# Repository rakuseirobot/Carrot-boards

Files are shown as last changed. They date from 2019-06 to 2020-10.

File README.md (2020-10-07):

# Carrot-boards
全自動走行台車の回路図です。
[Carrotの動画はこちら](https://www.youtube.com/watch?v=5gtot_12dCg&ab_channel=DDProjectII)

# Features

* STM32F7 Discovery用のボード
* KeyHolder FT234を使ったUSBシリアル変換器
* UI 操作板の基板データ　F4書き込みや、電源、リセットスイッチなどを載せる
* mainboard main基板　raspberryPiやSTM32F4が載ります

# Requirement

* Autodesk Eagleを用いて作成しました。

F4のプログラムは[こちら](https://github.com/rakuseirobot/Carrot-F4-motor)
RaspberryPiのプログラムは[こちら](https://github.com/rakuseirobot/Carrot-ROS-src)

# Note

mainboardに搭載されているSTM32F446に配線されているイーサネットICはLANコネクタを向きを逆に配置してしまったこととおそらく配線を間違ってしまったこともあり、実装すると3.3Vラインがショートしてしまうため注意してください。

# Author

* Shun Kayaki
* Kyushu institute of Technology
* shun@guetan.dev

# License

Copyright (c) 2019 Shun Kayaki
Released under the MIT license

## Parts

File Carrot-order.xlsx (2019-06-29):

部品名 | URL | 何個入り | 何個必要/板 | 何枚分？ | 何個必要 | 必要パック数 | 予備個数 | 購入パック数 | 購入個数 | 一パック当たりの値段 | 計 | 一枚当たりの計 | 備考 | 16440.44
51Ω チップ抵抗 | https://www.monotaro.com/g/04248178/?t.q=51%83%B6%81%40%83%60%83b%83v | 100 | 6 | 2 | 12 | 0.12 | 88 | 1 | 100 | 599 | 599 | 299.5
イーサネットICDP83848 | https://jp.rs-online.com/web/p/physical-layer-transceivers/6515738/ | 1 | 1 | 2 | 2 | 2 | 0 | 2 | 2 | 630.72 | 1261.44 | 630.72
 |  |  |  |  | 0 | #DIV/0! |  | #DIV/0! | 0 |  | #DIV/0! | #DIV/0!
 |  |  |  |  | 0 | #DIV/0! |  | #DIV/0! | 0 |  | #DIV/0! | #DIV/0!
 |  |  |  |  | 0 | #DIV/0! |  | #DIV/0! | 0 |  | #DIV/0! | #DIV/0!
CANコントローラー MCP2561 | http://akizukidenshi.com/catalog/g/gI-12483/ | 1 | 1 | 2 | 2 | 2 | 2 | 4 | 4 | 90 | 360 | 180
RS485コントローラーLTC485 | http://akizukidenshi.com/catalog/g/gI-02792/ | 1 | 1 | 2 | 2 | 2 | 2 | 4 | 4 | 150 | 600 | 300
50MHzクリスタル | http://akizukidenshi.com/catalog/g/gP-09358/ | 2 | 1 | 2 | 2 | 1 | 0 | 1 | 2 | 300 | 300 | 150
Nch MOSFET | http://akizukidenshi.com/catalog/g/gI-09931/ | 1 | 2 | 2 | 4 | 4 | 1 | 5 | 5 | 50 | 250 | 125
LANコネクタ | http://akizukidenshi.com/catalog/g/gP-04809/ | 1 | 1 | 2 | 2 | 2 |  | 2 | 2 | 200 | 400 | 200
DCファン | http://akizukidenshi.com/catalog/g/gP-14184/ | 1 | 1 | 2 | 2 | 2 |  | 2 | 2 | 280 | 560 | 280
ポリスイッチ350mA | http://akizukidenshi.com/catalog/g/gP-12900/ | 5 | 1 | 1 | 1 | 0.2 | 4 | 1 | 5 | 100 | 100 | 100
ポリスイッチ0.4A | http://akizukidenshi.com/catalog/g/gP-13077/ | 1 | 1 | 1 | 1 | 1 | 1 | 2 | 2 | 30 | 60 | 60
VH2ピン 基板側 | http://akizukidenshi.com/catalog/g/gC-12815/ | 1 | 4 | 2 | 8 | 8 | 1 | 9 | 9 | 10 | 90 | 45
VH2ピン 線側 | http://akizukidenshi.com/catalog/g/gC-12811/ | 1 | 10 | 1 | 10 | 10 |  | 10 | 10 | 7 | 70 | 70
VH3ピン 基板側 | http://akizukidenshi.com/catalog/g/gC-12816/ | 1 | 5 | 2 | 10 | 10 | 4 | 14 | 14 | 10 | 140 | 70
VH3ピン 線側 | http://akizukidenshi.com/catalog/g/gC-12812/ | 1 | 10 | 1 | 10 | 10 |  | 10 | 10 | 8 | 80 | 80
VH コンタクト | http://akizukidenshi.com/catalog/g/gC-12819/ | 10 | 10 | 10 | 100 | 10 |  | 10 | 100 | 50 | 500 | 50
4.7uF | http://akizukidenshi.com/catalog/g/gP-13605/ | 20 | 2 | 2 | 4 | 0.2 | 16 | 1 | 20 | 160 | 160 | 80
22pF | http://akizukidenshi.com/catalog/g/gP-13313/ | 40 | 2 | 2 | 4 | 0.1 | 36 | 0 | 40 | 100 | 0 | 0 | ある
22uF | http://akizukidenshi.com/catalog/g/gP-08240/ | 10 | 2 | 2 | 4 | 0.4 | 6 | 1 | 10 | 120 | 120 | 60
10uF | http://akizukidenshi.com/catalog/g/gP-13388/ | 10 | 2 | 2 | 4 | 0.4 | 6 | 0 | 10 | 150 | 0 | 0 | ある
100uF チップ電解 | http://akizukidenshi.com/catalog/g/gP-06855/ | 1 | 3 | 2 | 6 | 6 | 1 | 4 | 7 | 150 | 600 | 300 | ４こある
タクトスイッチ黄色 | http://akizukidenshi.com/catalog/g/gP-03650/ | 1 | 1 | 2 | 2 | 2 |  | 0 | 2 | 10 | 0 | 0 | ある
タクトスイッチ赤色 | http://akizukidenshi.com/catalog/g/gP-03646/ | 1 | 1 | 2 | 2 | 2 |  | 0 | 2 | 10 | 0 | 0 | ある
4.7kΩ アレイ | http://akizukidenshi.com/catalog/g/gP-04663/ | 100 | 2 | 2 | 4 | 0.04 | 96 | 0 | 100 | 100 | 0 | 0 | ある
圧電ブザー | http://akizukidenshi.com/catalog/g/gP-04119/ | 1 | 1 | 2 | 2 | 2 | 1 | 3 | 3 | 40 | 120 | 60
水晶発振子 8MHz | http://akizukidenshi.com/catalog/g/gP-08667/ | 1 | 1 | 2 | 2 | 2 | 0 | 2 | 2 | 30 | 60 | 30
スライドスイッチ | http://akizukidenshi.com/catalog/g/gP-12723/ | 1 | 4 | 2 | 8 | 8 | 2 | 10 | 10 | 25 | 250 | 125
DCジャック | http://akizukidenshi.com/catalog/g/gC-06730/ | 1 | 1 | 2 | 2 | 2 |  | 0 | 2 | 130 | 0 | 0 | ある
ボックスヘッダ 7*2 | http://akizukidenshi.com/catalog/g/gC-10901/ | 1 | 2 | 2 | 4 | 4 | 3 | 4 | 7 | 25 | 100 | 50 | ある
ムラタDCDCコンバータ | http://akizukidenshi.com/catalog/g/gM-06187/ | 1 | 2 | 2 | 4 | 4 |  | 3 | 4 | 600 | 1800 | 900 | 1個ある
USBA ホスト側 | http://akizukidenshi.com/catalog/g/gC-11551/ | 1 | 1 | 2 | 2 | 2 |  | 2 | 2 | 50 | 100 | 50
20kΩ 多回転 半固定抵抗 | http://akizukidenshi.com/catalog/g/gP-01032/ | 1 | 2 | 2 | 4 | 4 |  | 0 | 4 | 120 | 0 | 0 | ある
RaspberryPi コネクタ | http://akizukidenshi.com/catalog/g/gC-10702/ | 1 | 1 | 2 | 2 | 2 |  | 2 | 2 | 150 | 300 | 150
表面実装タクトスイッチ | http://akizukidenshi.com/catalog/g/gP-06185/ | 5 | 2 | 2 | 4 | 0.8 | 1 | 1 | 5 | 100 | 100 | 50
Pch MOSFET J334 | http://akizukidenshi.com/catalog/g/gI-02846/ | 1 | 4 | 2 | 8 | 8 |  | 8 | 8 | 150 | 1200 | 600
2mmピッチ ピンソケット | http://akizukidenshi.com/catalog/g/gC-03668/ | 1 | 2 | 2 | 4 | 4 |  | 4 | 4 | 30 | 120 | 60
ICソケット 8P | http://akizukidenshi.com/catalog/g/gP-00017/ | 10 | 2 | 2 | 4 | 0.4 | 6 | 1 | 10 | 100 | 100 | 50
ターミナルブロック | http://akizukidenshi.com/catalog/g/gP-01306/ | 1 | 4 | 2 | 8 | 8 |  | 8 | 8 | 20 | 160 | 80
緑色LED入り タクトスイッチ | http://akizukidenshi.com/catalog/g/gP-02009/ | 1 | 1 | 1 | 1 | 1 |  | 1 | 1 | 150 | 150 | 150
赤色LED入り タクトスイッチ | http://akizukidenshi.com/catalog/g/gP-02010/ | 1 | 1 | 1 | 1 | 1 |  | 1 | 1 | 150 | 150 | 150
キースイッチ | http://akizukidenshi.com/catalog/g/gP-07059/ | 1 | 2 | 1 | 2 | 2 |  | 2 | 2 | 100 | 200 | 200
緑色LED トグルスイッチ | http://akizukidenshi.com/catalog/g/gP-07246/ | 1 | 2 | 1 | 2 | 2 |  | 2 | 2 | 200 | 400 | 400
3ピンDIPスイッチ | http://akizukidenshi.com/catalog/g/gP-09992/ | 1 | 1 | 1 | 1 | 1 |  | 1 | 1 | 80 | 80 | 80 | あったと。。
 |  |  |  |  | 0 | #DIV/0! |  | #DIV/0! | 0 |  | #DIV/0! | #DIV/0!
STMF405 | http://akizukidenshi.com/catalog/g/gI-13219/ | 1 | 2 | 1 | 2 | 2 |  | 2 | 2 | 1000 | 2000 | 2000
 |  |  |  |  | 0 | #DIV/0! |  | #DIV/0! | 0 |  | #DIV/0! | #DIV/0!
LCD LED | http://akizukidenshi.com/catalog/g/gI-05318/ | 20 | 1 | 12 | 12 | 0.6 | 8 | 1 | 20 | 200 | 200 | 16.66666667
FT230 | http://akizukidenshi.com/catalog/g/gI-13311/ | 1 | 1 | 10 | 10 | 10 |  | 10 | 10 | 220 | 2200 | 220
ポリスイッチ350mA | http://akizukidenshi.com/catalog/g/gP-12900/ | 5 | 1 | 7 | 7 | 1.4 | 3 | 2 | 10 | 100 | 200 | 28.57142857
白色チップLED | http://akizukidenshi.com/catalog/g/gI-03986/ | 20 | 1 | 1 | 1 | 0.05 | 19 | 1 | 20 | 200 | 200 | 200
青色チップLED | http://akizukidenshi.com/catalog/g/gI-03982/ | 20 | 1 | 1 | 1 | 0.05 | 19 | 0 | 20 | 200 | 0 | 0 | ある
赤色チップLED | http://akizukidenshi.com/catalog/g/gI-03978/ | 20 | 1 | 1 | 1 | 0.05 | 19 | 0 | 20 | 200 | 0 | 0 | ある
 |  |  |  |  | 0 | #DIV/0! |  | #DIV/0! | 0 |  | #DIV/0! | #DIV/0!
 |  |  |  |  | 0 | #DIV/0! |  | #DIV/0! | 0 |  | #DIV/0! | #DIV/0!
 |  |  |  |  | 0 | #DIV/0! |  | #DIV/0! | 0 |  | #DIV/0! | #DIV/0!
 |  |  |  |  | 0 | #DIV/0! |  | #DIV/0! | 0 |  | #DIV/0! | #DIV/0!
 |  |  |  |  | 0 | #DIV/0! |  | #DIV/0! | 0 |  | #DIV/0! | #DIV/0!
 |  |  |  |  | 0 | #DIV/0! |  | #DIV/0! | 0 |  | #DIV/0! | #DIV/0!
 |  |  |  |  | 0 | #DIV/0! |  | #DIV/0! | 0 |  | #DIV/0! | #DIV/0!
 |  |  |  |  | 0 | #DIV/0! |  | #DIV/0! | 0 |  | #DIV/0! | #DIV/0!
 |  |  |  |  | 0 | #DIV/0! |  | #DIV/0! | 0 |  | #DIV/0! | #DIV/0!
 |  |  |  |  |  |  |  |  |  |  | #DIV/0! | #DIV/0!

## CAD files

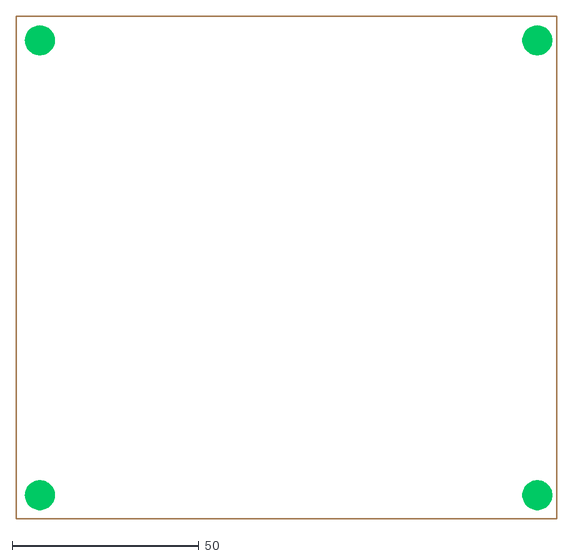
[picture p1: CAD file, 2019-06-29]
mainboard.dxf
144.9 x 134.8

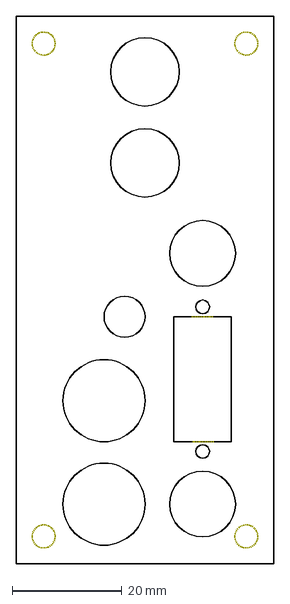
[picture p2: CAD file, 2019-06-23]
UI.dxf
47.0 x 100.0 mm

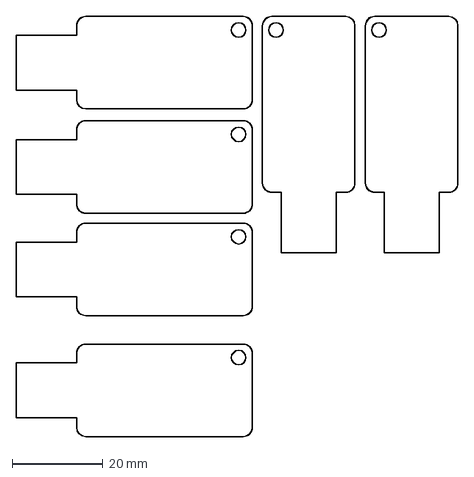
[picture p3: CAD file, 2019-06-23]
KeyHolder.dxf
97.4 x 92.6 mm

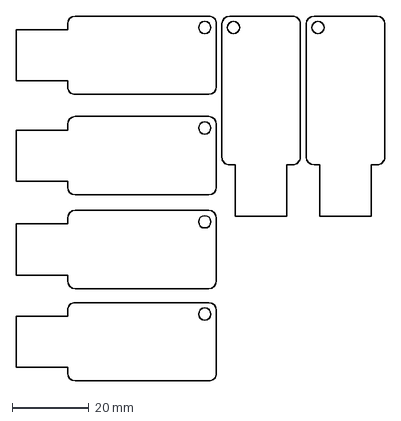
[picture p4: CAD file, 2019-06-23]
UIboard.dxf
95.9 x 95.0 mm

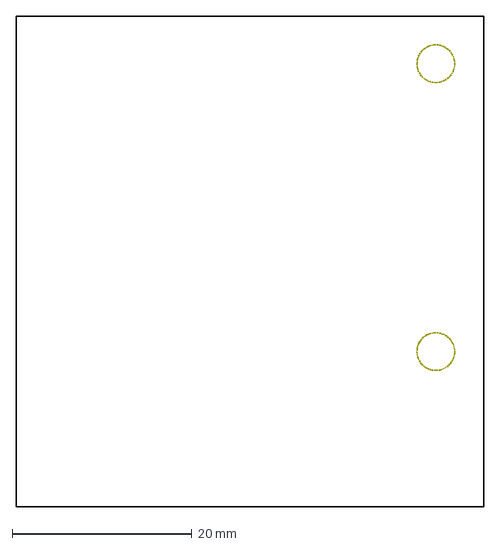
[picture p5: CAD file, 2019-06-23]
F7.dxf
52.1 x 54.6 mm

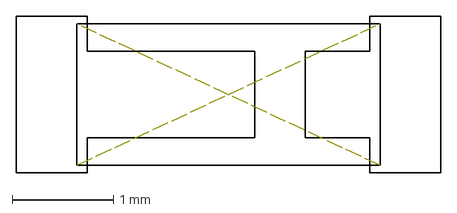
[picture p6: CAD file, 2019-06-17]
NSSW157T.dxf
4.20 x 1.55 mm

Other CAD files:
Carrot.dxf
F7&Key&UI-shape.ipt
F7.ipt
NSSW157T.ipt
OldVersions/F7&Key&UI-shape.0003.ipt
OldVersions/UI.0001.ipt
OldVersions/USB.0001.ipt
UI.ipt
USB.ipt

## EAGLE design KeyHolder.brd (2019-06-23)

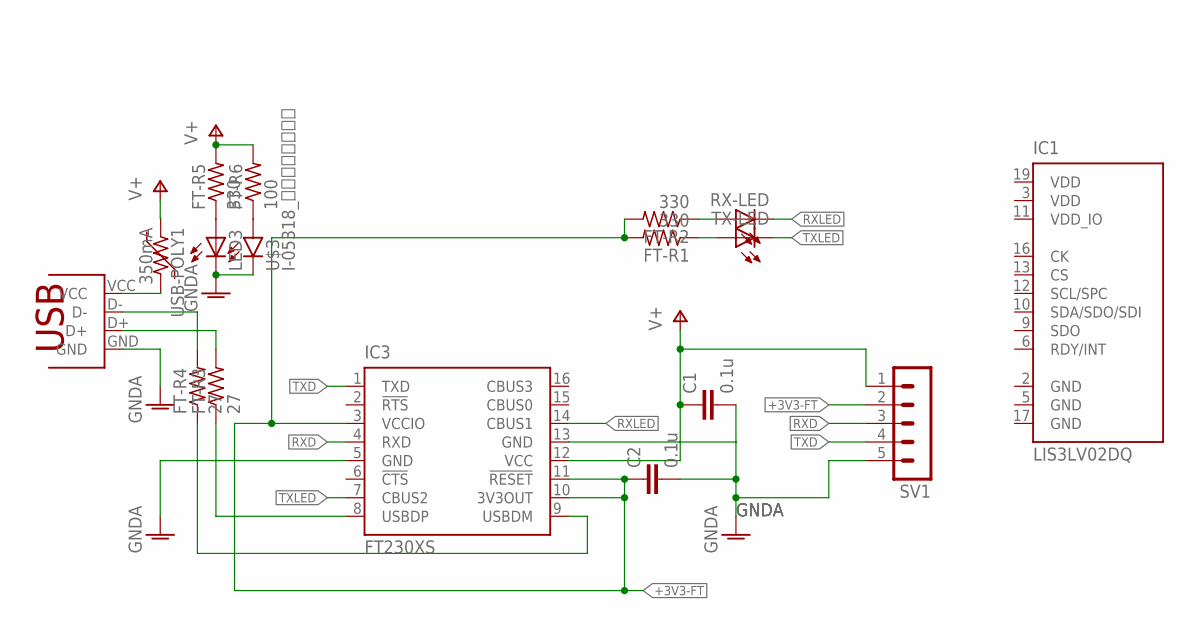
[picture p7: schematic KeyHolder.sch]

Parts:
C1, C2: 0.1u; C1608
FT-R1, FT-R2, FT-R5: 330; R0805
FT-R3, FT-R4: 27; R0805
FT-R6: 100; R0805
IC1: LIS3LV02DQ; QFPN-28
IC3: FT230XS; SSOP16
LED3: LEDCHIP-LED0805; CHIP-LED0805
RX-LED: LEDCHIP-LED0805; CHIP-LED0805
SV1: MA05-1
TX-LED: LEDCHIP-LED0805; CHIP-LED0805
U$2: USB-PAD; USB
U$3: I-05318_ＮＳＳＷ１５７Ｔ; NSSW157T
USB-POLY1: 350mA; F0805MP

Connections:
+3V3-FT: C2.1, FT-R1.2, FT-R2.2, IC3.3 (VCCIO), IC3.10 (3V3OUT), IC3.11 (!RESET), SV1.2
GND: IC1.2 (GND), IC1.5 (GND), IC1.17 (GND)
GNDA: C1.2, C2.2, IC3.5 (GND), IC3.13 (GND), LED3.C, SV1.5, U$2.GND, U$3.CATHODE (C)
unnamed: FT-R2.1, RX-LED.A
unnamed: FT-R1.1, TX-LED.A
unnamed: FT-R3.2, U$2.D+
unnamed: FT-R3.1, IC3.8 (USBDP)
unnamed: FT-R4.1, IC3.9 (USBDM)
unnamed: FT-R4.2, U$2.D-
unnamed: U$2.VCC, USB-POLY1.2
unnamed: FT-R5.1, LED3.A
unnamed: FT-R6.1, U$3.ANODE (A)
RXD: IC3.4 (RXD), SV1.3
RXLED: IC3.14 (CBUS1), RX-LED.C
TXD: IC3.1 (TXD), SV1.4
TXLED: IC3.7 (CBUS2), TX-LED.C
V+: C1.1, FT-R5.2, FT-R6.2, IC3.12 (VCC), SV1.1, USB-POLY1.1
VDD: IC1.3 (VDD), IC1.19 (VDD)
VDD_IO: IC1.11 (VDD_IO)

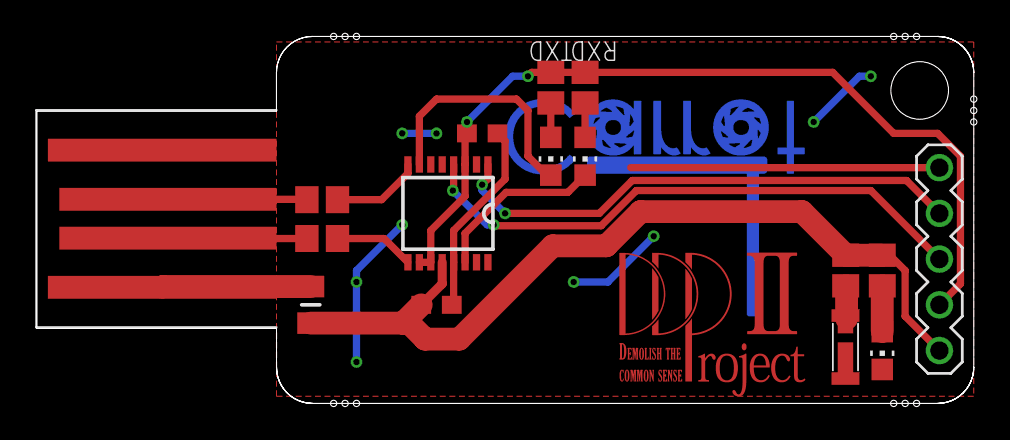
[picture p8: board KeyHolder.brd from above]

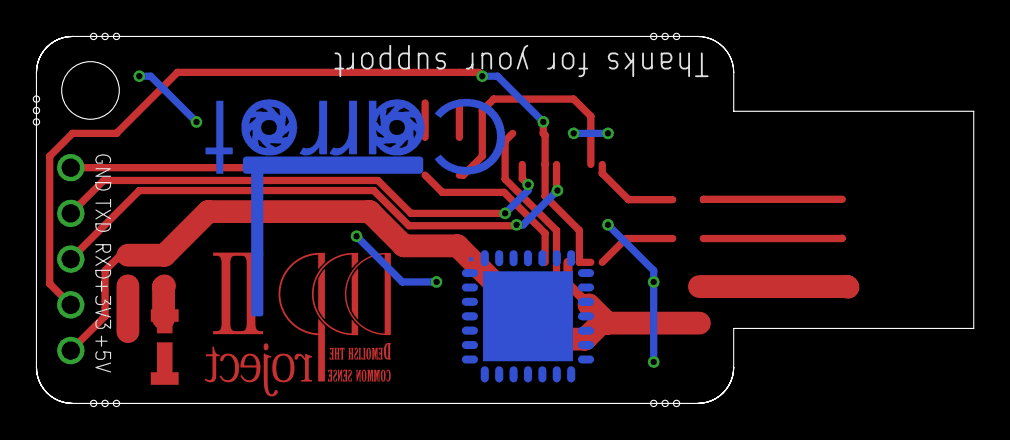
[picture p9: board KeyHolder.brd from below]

Board: 2 copper layers, 52.1 x 20.4 mm, 19 parts (2 on the bottom side), 18 nets.

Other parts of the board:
U$5: CARROT
U$6: DDPROJECT2-TOP

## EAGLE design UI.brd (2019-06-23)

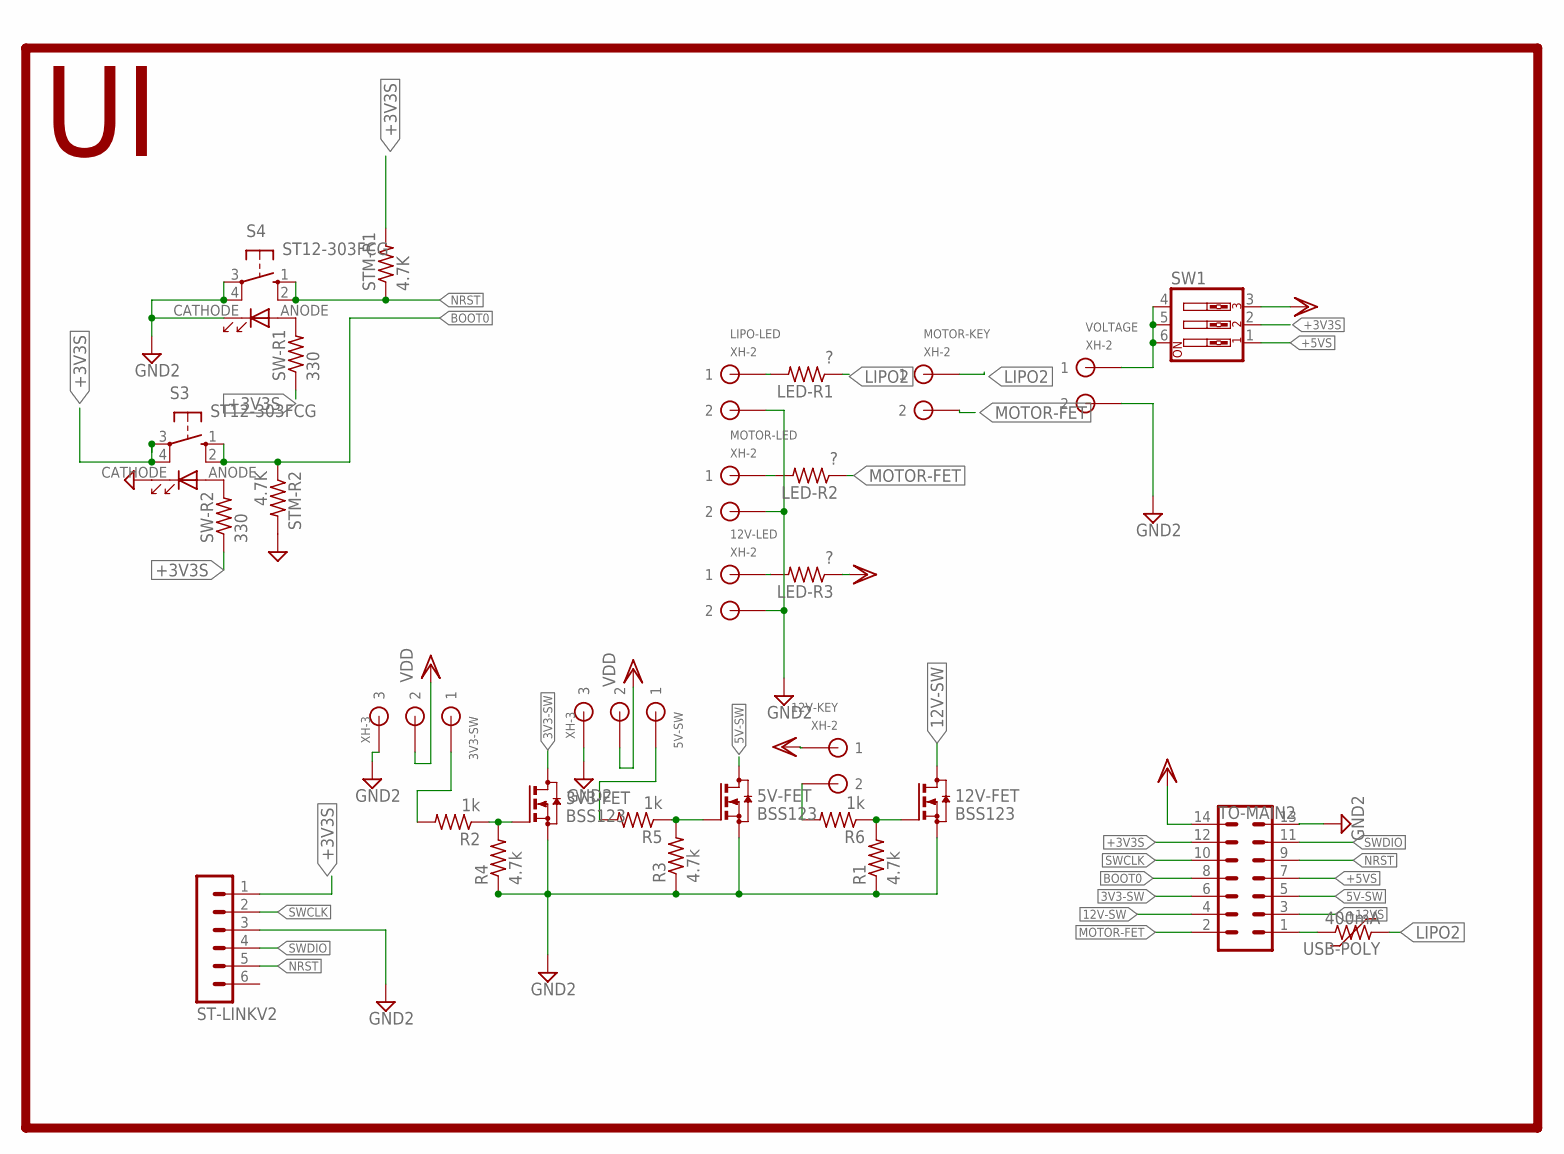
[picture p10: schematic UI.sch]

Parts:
3V3-FET, 5V-FET, 12V-FET: BSS123; SOT23
3V3-SW, 5V-SW: XH-3; CON3
12V-KEY, 12V-LED: XH-2; CON2
LED-R1, LED-R2, LED-R3: ?; M0805
LIPO-LED: XH-2; CON2
MOTOR-KEY: XH-2; CON2
MOTOR-LED: XH-2; CON2
R1, R3, R4: 4.7k; M0805
R2, R5, R6: 1k; M0805
S3, S4: ST12-303FCG; ST12303FCG
ST-LINKV2: MA06-1
STM-R1, STM-R2: 4.7K; R0805
SW1: SW_DIP-3; EDG-03
SW-R1, SW-R2: 330; R0805
TO-MAIN2: ML14
USB-POLY: 400mA; MF-5/1
VOLTAGE: XH-2; CON2

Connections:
3V3-SW: 3V3-FET.3 (D), TO-MAIN2.6
5V-SW: 5V-FET.3 (D), TO-MAIN2.5
12V-SW: 12V-FET.3 (D), TO-MAIN2.4
+3V3S: S3.3, S3.4, ST-LINKV2.1, STM-R1.2, SW1.2, SW-R1.1, SW-R2.1, TO-MAIN2.12
+5VS: SW1.1, TO-MAIN2.7
+12VS: TO-MAIN2.3
BOOT0: S3.1, S3.2, STM-R2.1, TO-MAIN2.8
GND2: 3V3-FET.2 (S), 3V3-SW.P$3 (3), 5V-FET.2 (S), 5V-SW.P$3 (3), 12V-FET.2 (S), 12V-LED.P$2 (2), LIPO-LED.P$2 (2), MOTOR-LED.P$2 (2), R1.1, R3.1, R4.1, S3.CATHODE (C), S4.3, S4.4, S4.CATHODE (C), ST-LINKV2.3, STM-R2.2, TO-MAIN2.13, VOLTAGE.P$2 (2)
LIPO2: LED-R1.1, MOTOR-KEY.P$1 (1), USB-POLY.1
MOTOR-FET: LED-R2.1, MOTOR-KEY.P$2 (2), TO-MAIN2.2
unnamed: 3V3-FET.1 (G), R2.1, R4.2
unnamed: 5V-FET.1 (G), R3.2, R5.1
unnamed: SW1.4, SW1.5, SW1.6, VOLTAGE.P$1 (1)
unnamed: 12V-FET.1 (G), R1.2, R6.1
unnamed: 12V-KEY.P$2 (2), R6.2
unnamed: 3V3-SW.P$1 (1), R2.2
unnamed: 5V-SW.P$1 (1), R5.2
unnamed: S4.ANODE (A), SW-R1.2
unnamed: S3.ANODE (A), SW-R2.2
unnamed: TO-MAIN2.1, USB-POLY.2
unnamed: LED-R1.2, LIPO-LED.P$1 (1)
unnamed: LED-R2.2, MOTOR-LED.P$1 (1)
unnamed: 12V-LED.P$1 (1), LED-R3.2
NRST: S4.1, S4.2, ST-LINKV2.5, STM-R1.1, TO-MAIN2.9
SWCLK: ST-LINKV2.2, TO-MAIN2.10
SWDIO: ST-LINKV2.4, TO-MAIN2.11
VDD: 3V3-SW.P$2 (2), 5V-SW.P$2 (2), 12V-KEY.P$1 (1), LED-R3.1, SW1.3, TO-MAIN2.14

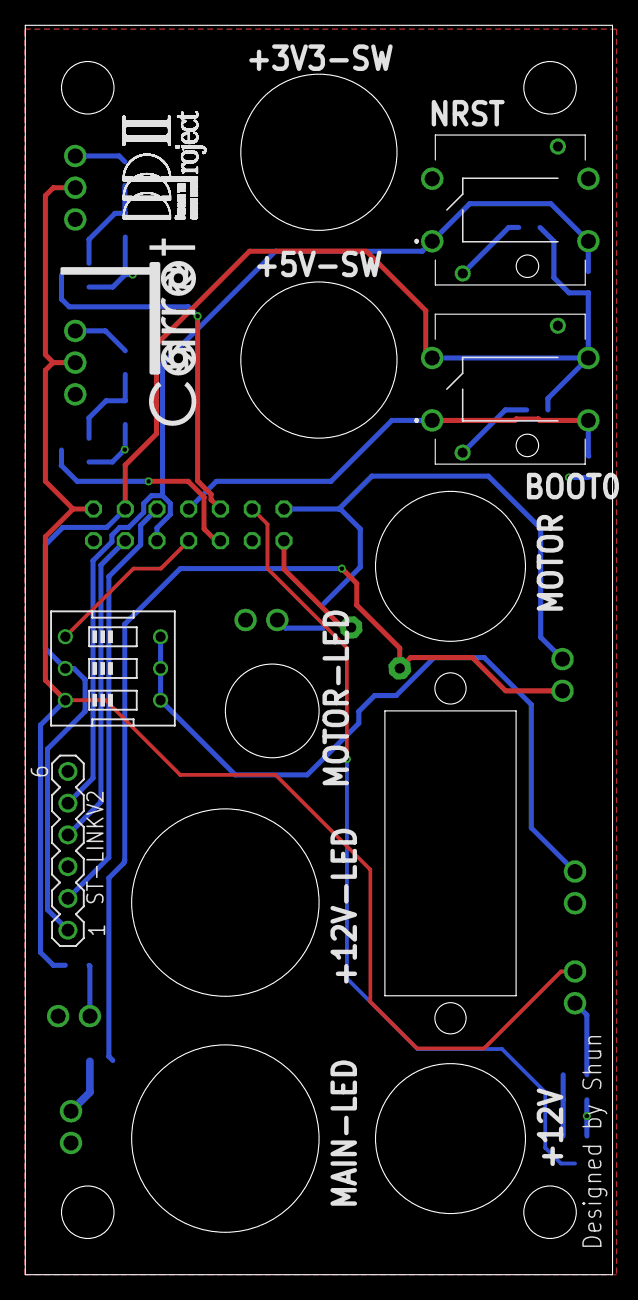
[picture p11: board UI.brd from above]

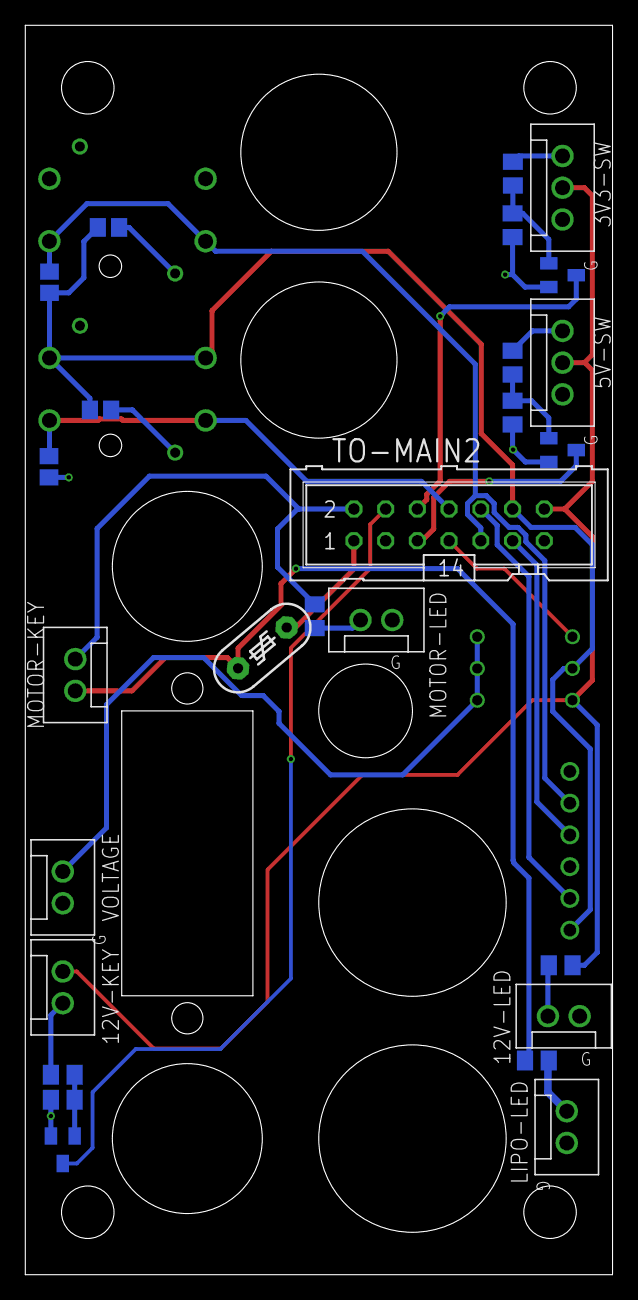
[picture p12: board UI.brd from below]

Board: 2 copper layers, 47.0 x 100.0 mm, 32 parts (26 on the bottom side), 26 nets.

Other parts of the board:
U$7: CARROT-SILK
U$8: DDPROJECT2

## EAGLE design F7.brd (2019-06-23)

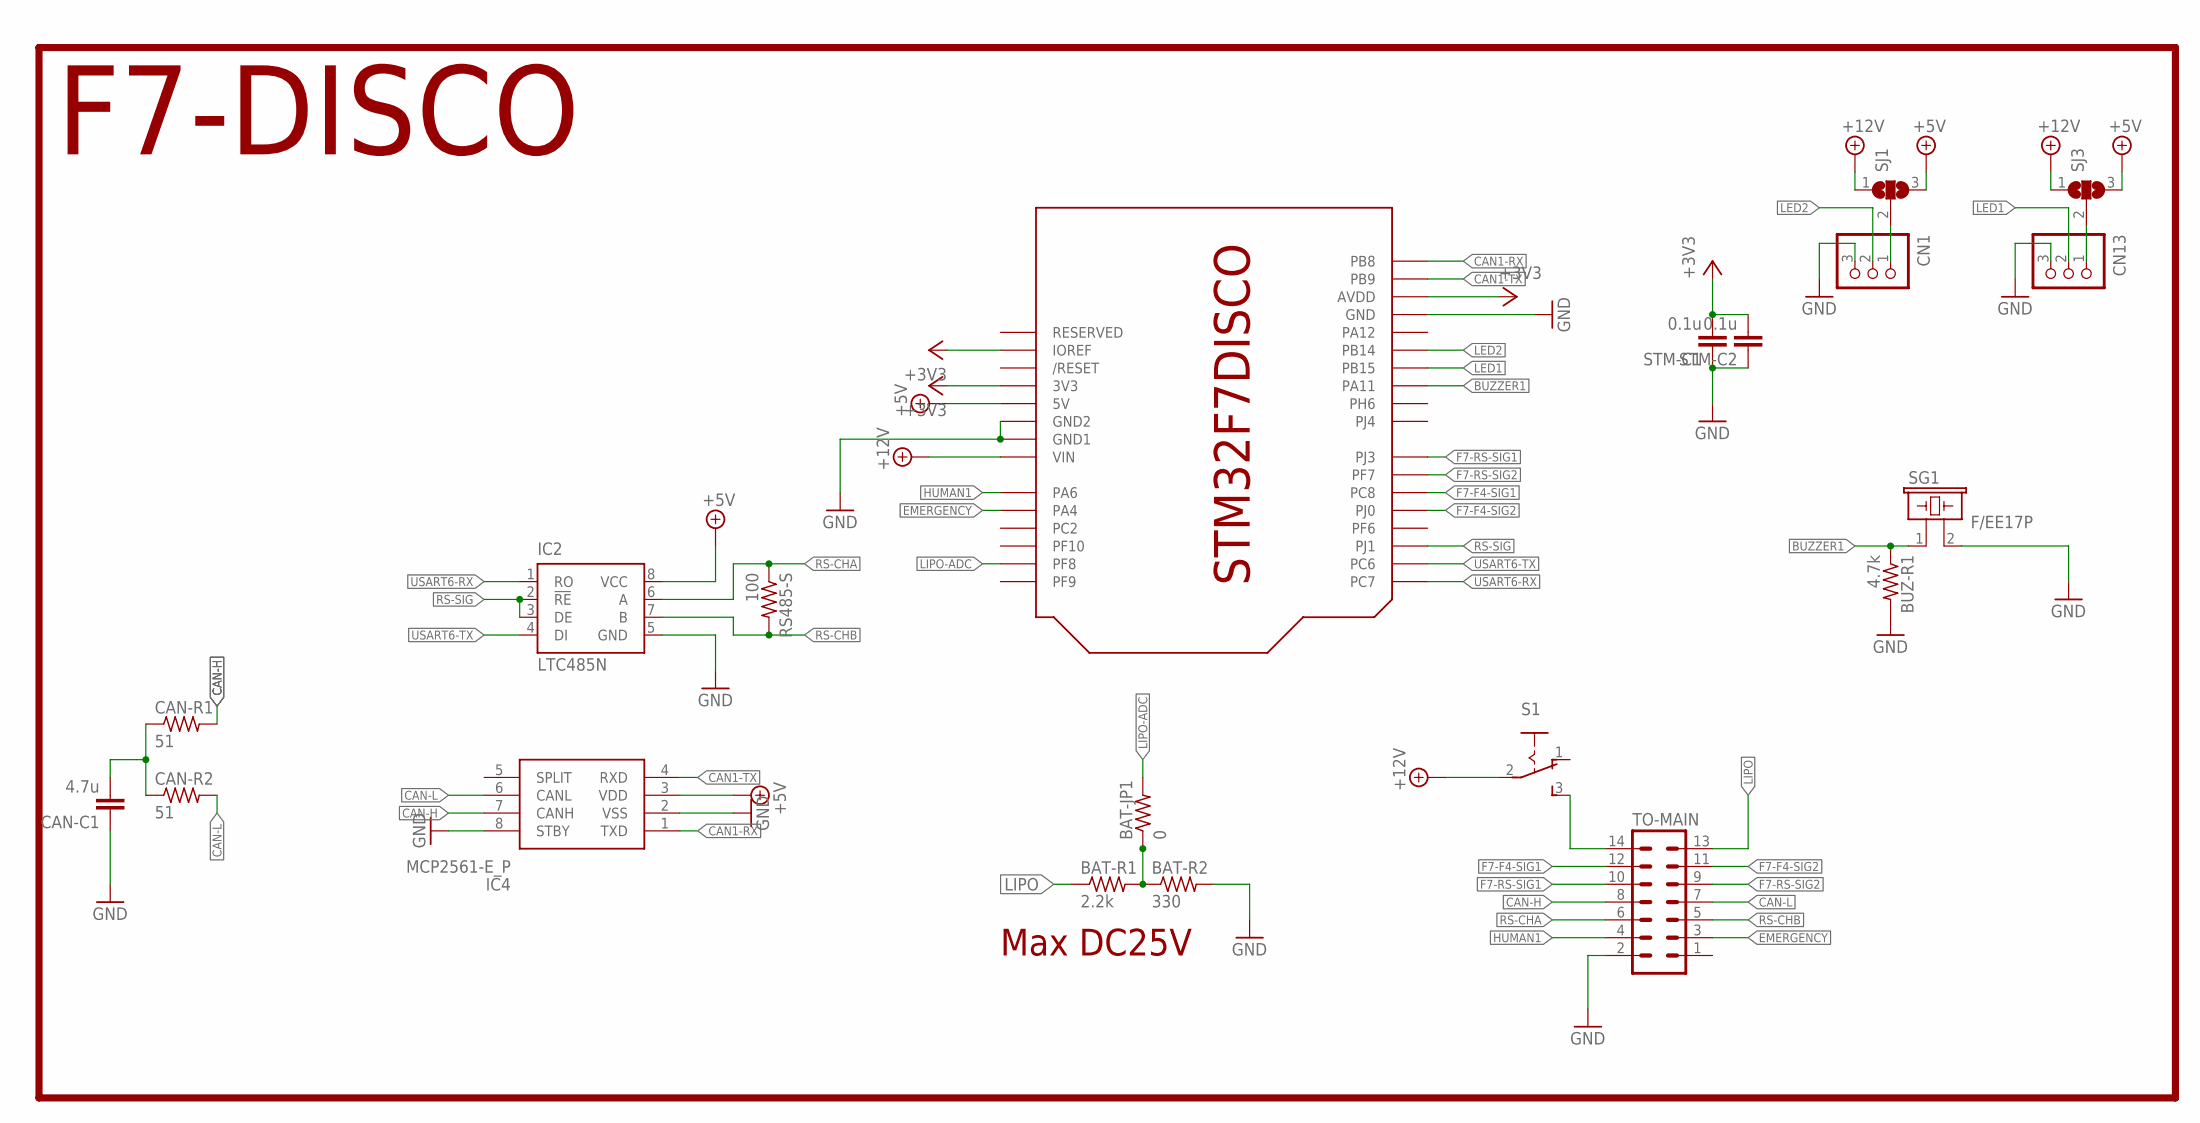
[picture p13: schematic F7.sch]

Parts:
BAT-JP1: 0; R0805
BAT-R1: 2.2k; R0805
BAT-R2: 330; R0805
BUZ-R1: 4.7k; R0805
CAN-C1: 4.7u; C0805
CAN-R1, CAN-R2: 51; R0805
CN1, CN13: B3P-VH
IC2: LTC485N; DIL08
IC4: MCP2561-E_P; DIP781W56P254L950H533Q8N
RS485-S: 100; R0805
S1: 255SB
SG1: F/EE17P
SJ1, SJ3: SJ2WW; SJ_2W
STM-C1, STM-C2: 0.1u; C0805
TO-MAIN: ML14
U$1: F7-DISCO-ARDUINO

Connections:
+5V: IC2.8 (VCC), IC4.3 (VDD), SJ1.3, SJ3.3, U$1.5V
+9V: S1.2, SJ1.1, SJ3.1, U$1.VIN
+12V: S1.3 (S), TO-MAIN.14
BUZZER1: BUZ-R1.1, SG1.1, U$1.PA11
CAN1-RX: IC4.1 (TXD), U$1.PB8
CAN1-TX: IC4.4 (RXD), U$1.PB9
CAN-H: CAN-R1.2, IC4.7 (CANH), TO-MAIN.8
CAN-L: CAN-R2.2, IC4.6 (CANL), TO-MAIN.7
EMERGENCY: TO-MAIN.3, U$1.PA4
F7-F4-SIG1: TO-MAIN.12, U$1.PC8
F7-F4-SIG2: TO-MAIN.11, U$1.PJ0
F7-RS-SIG1: TO-MAIN.10, U$1.PJ3
F7-RS-SIG2: TO-MAIN.9, U$1.PF7
GND: BAT-R2.2, BUZ-R1.2, CAN-C1.1, CN1.3, CN13.3, IC2.5 (GND), IC4.2 (VSS), IC4.8 (STBY), SG1.2, STM-C1.1, STM-C2.1, TO-MAIN.2, U$1.GND1 (GND), U$1.GND@1 (GND1), U$1.GND@2 (GND2)
HUMAN1: TO-MAIN.4, U$1.PA6
LED1: CN13.2, U$1.PB15
LED2: CN1.2, U$1.PB14
LIPO: BAT-R1.1, TO-MAIN.13
LIPO-ADC: BAT-JP1.2, U$1.PF8
unnamed: CN1.1, SJ1.2
unnamed: CAN-C1.2, CAN-R1.1, CAN-R2.1
unnamed: BAT-JP1.1, BAT-R1.2, BAT-R2.1
unnamed: CN13.1, SJ3.2
RS-CHA: IC2.6 (A), RS485-S.1, TO-MAIN.6
RS-CHB: IC2.7 (B), RS485-S.2, TO-MAIN.5
RS-SIG: IC2.2 (!RE), IC2.3 (DE), U$1.PJ1
USART6-RX: IC2.1 (RO), U$1.PC7
USART6-TX: IC2.4 (DI), U$1.PC6
VCC: STM-C1.2, STM-C2.2, U$1.3V (3V3), U$1.AVDD, U$1.IOREF

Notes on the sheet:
Max DC25V
F7-DISCO

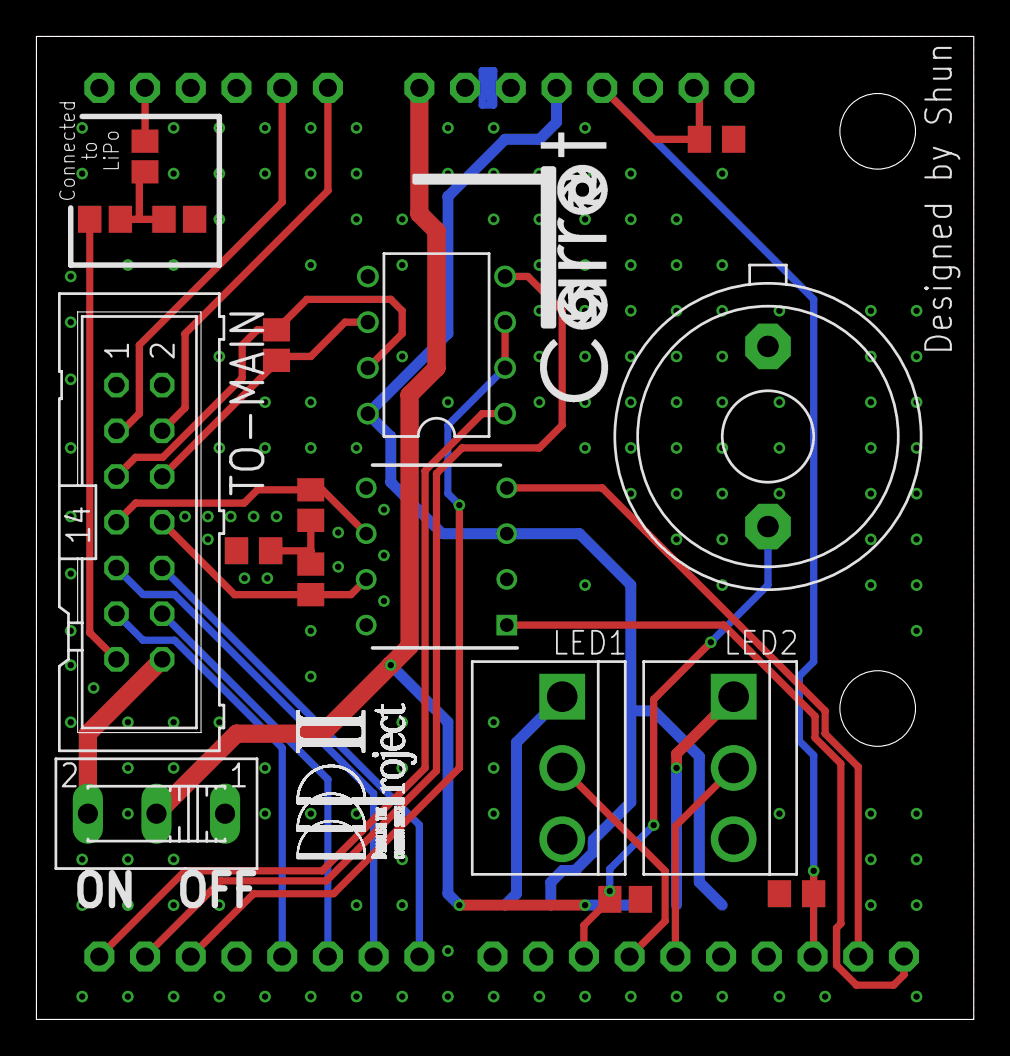
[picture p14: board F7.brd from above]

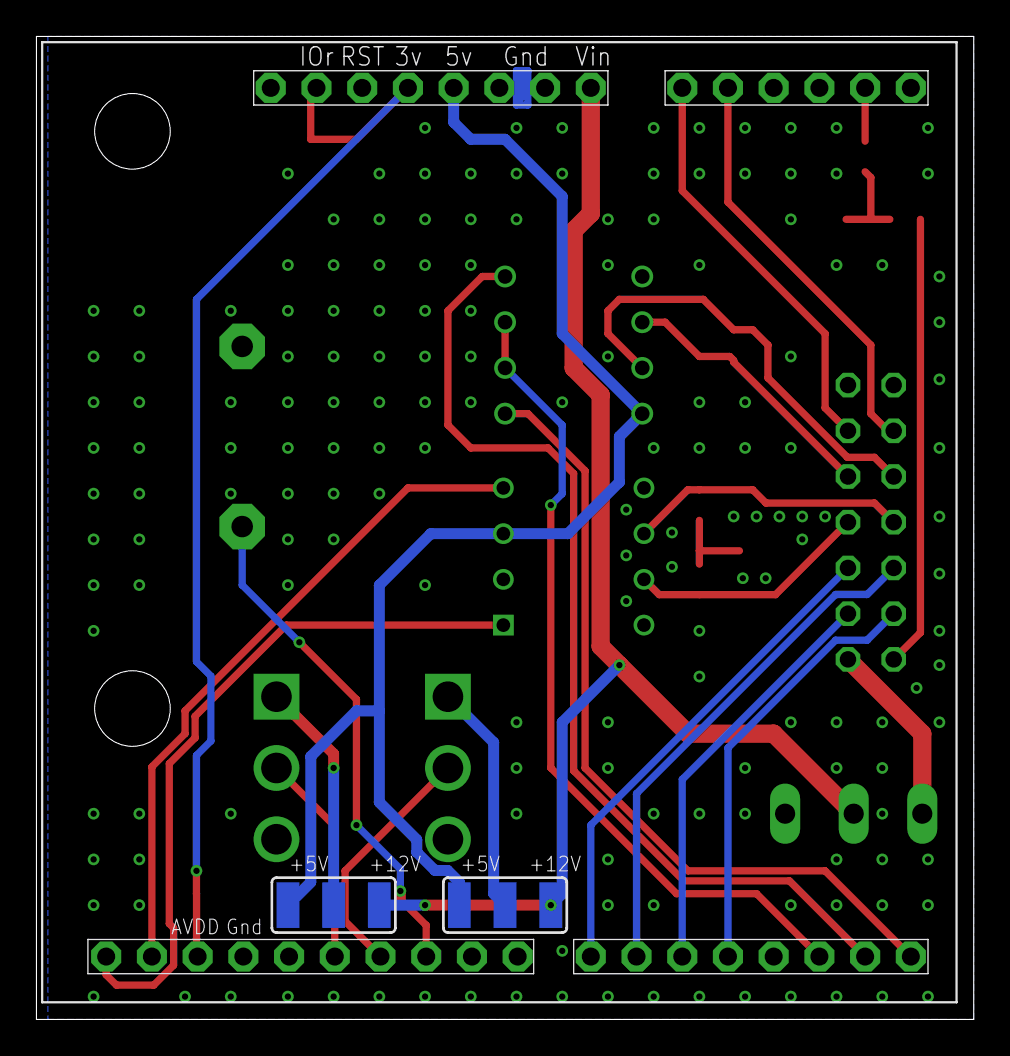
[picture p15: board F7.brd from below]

Board: 2 copper layers, 52.1 x 54.6 mm, 22 parts (3 on the bottom side), 29 nets.

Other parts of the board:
U$4: CARROT-SILK
U$9: DDPROJECT2

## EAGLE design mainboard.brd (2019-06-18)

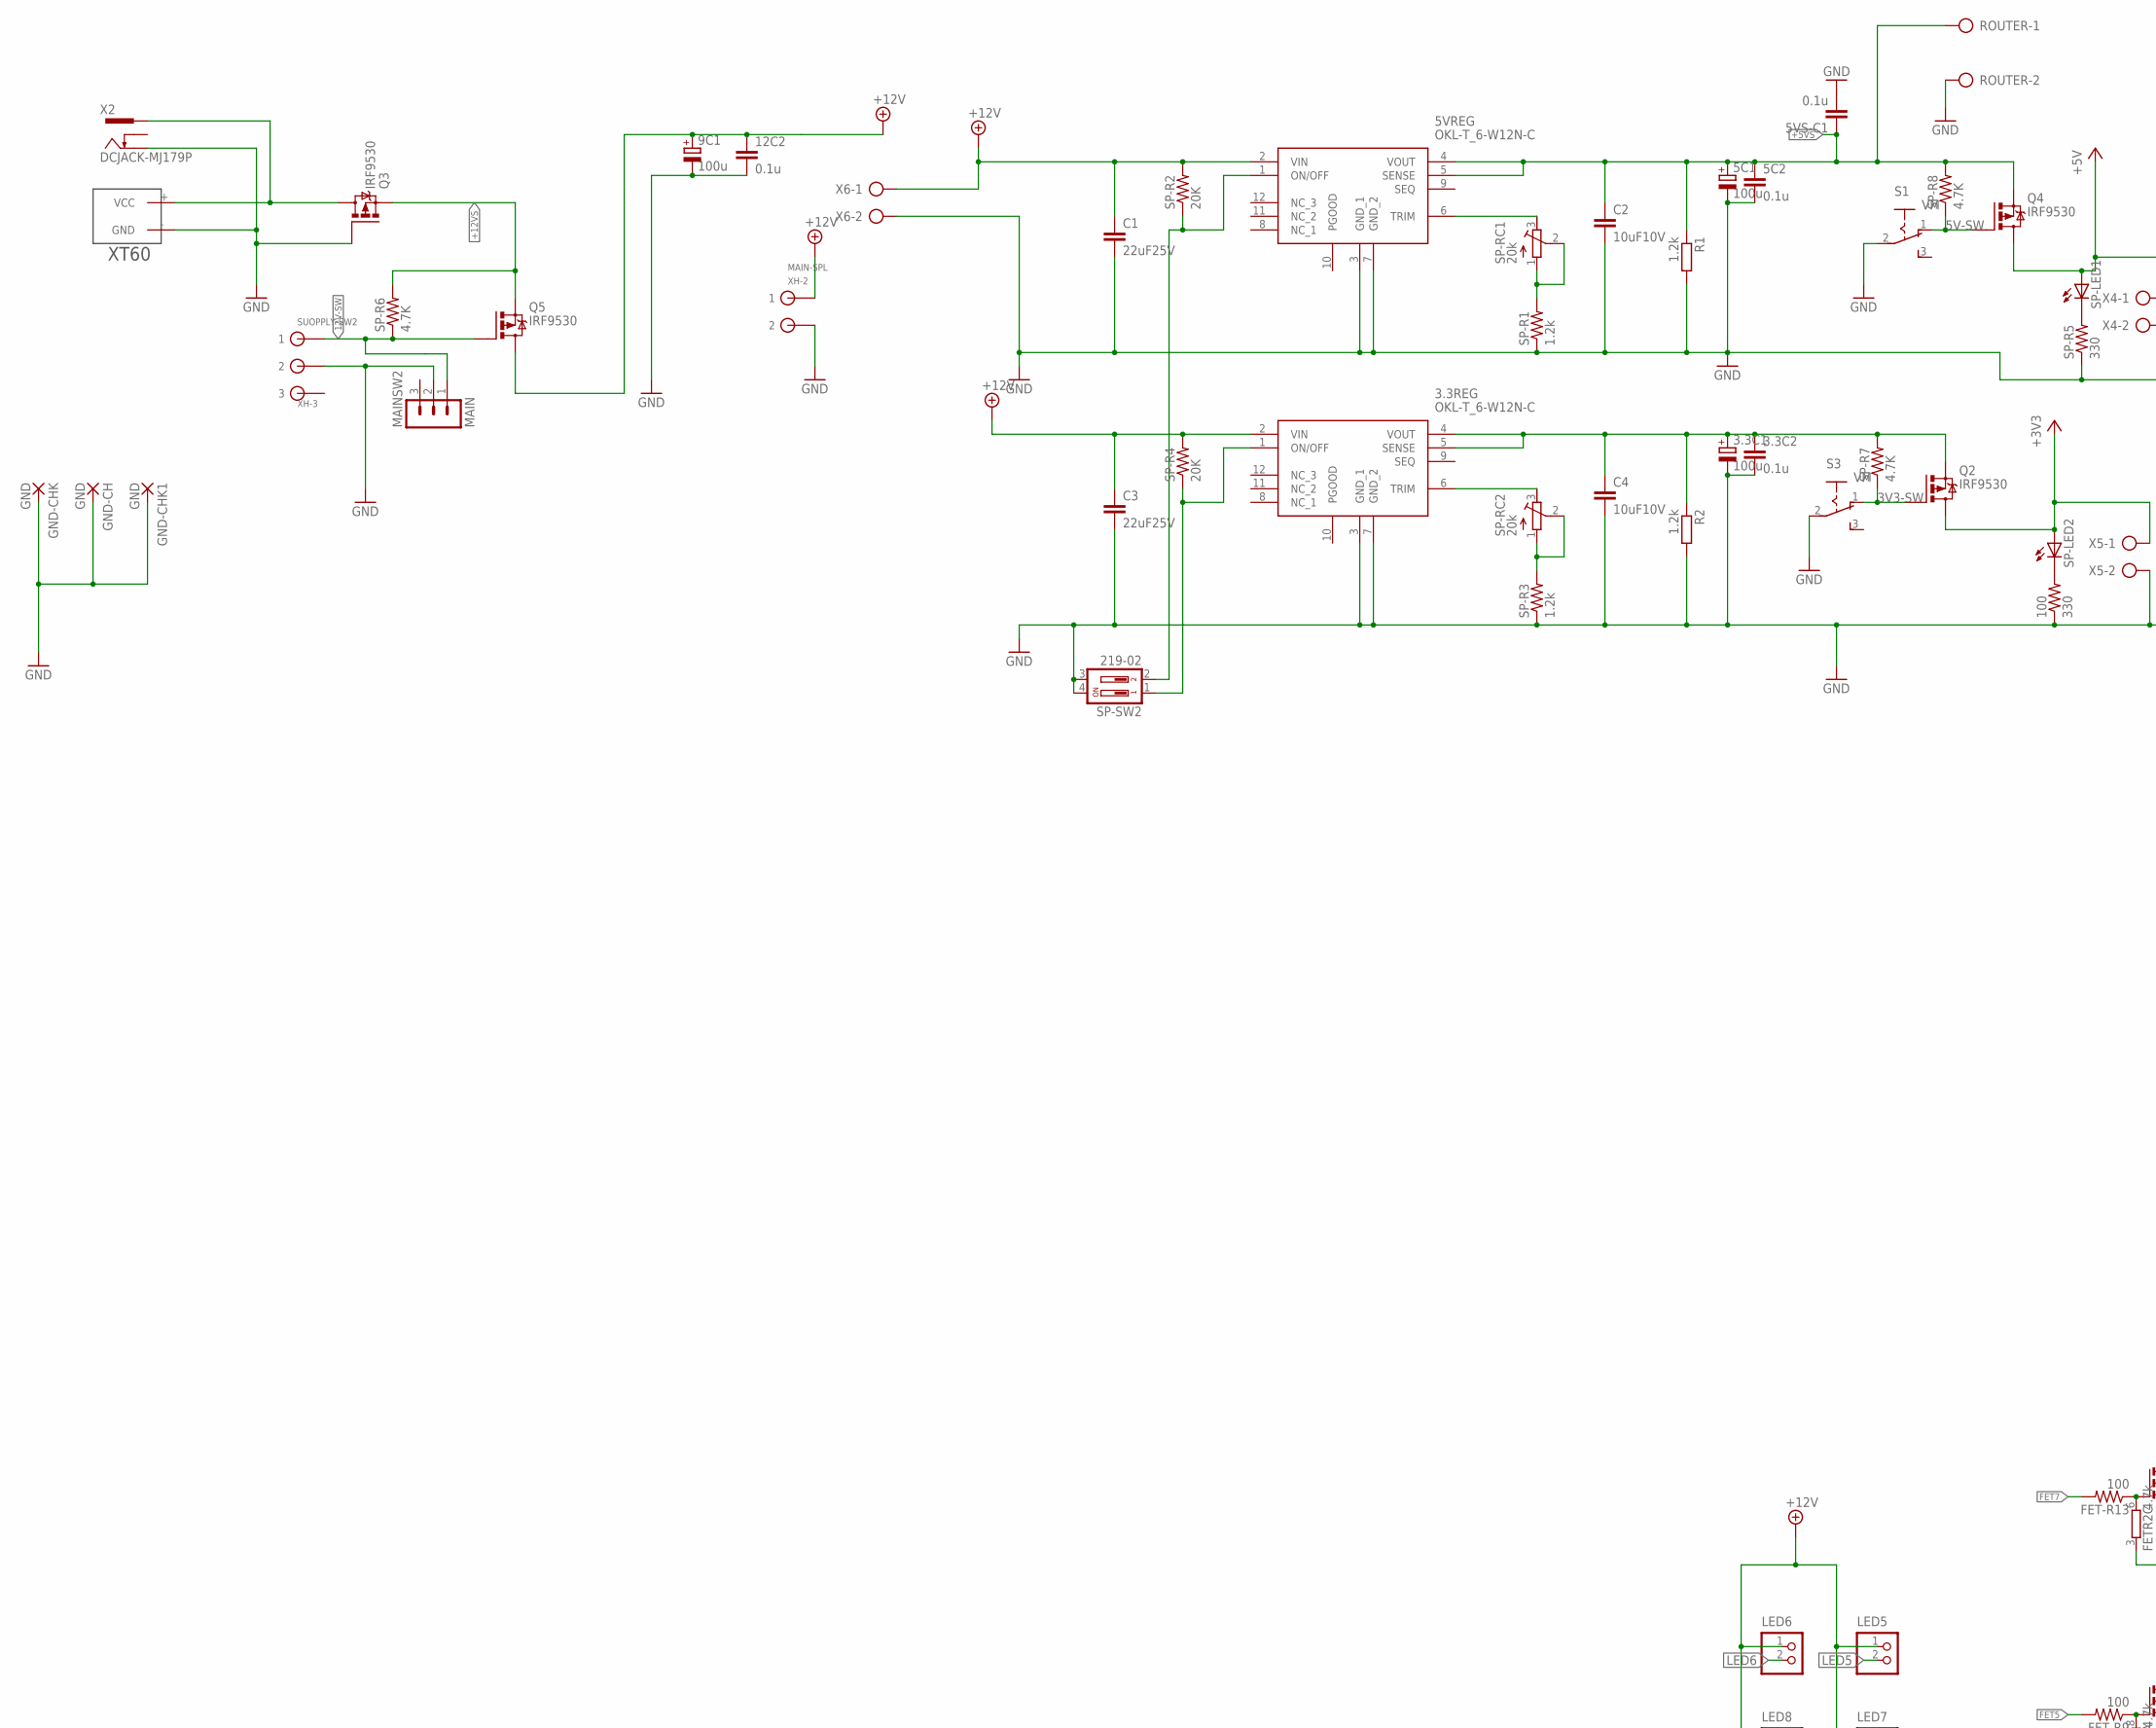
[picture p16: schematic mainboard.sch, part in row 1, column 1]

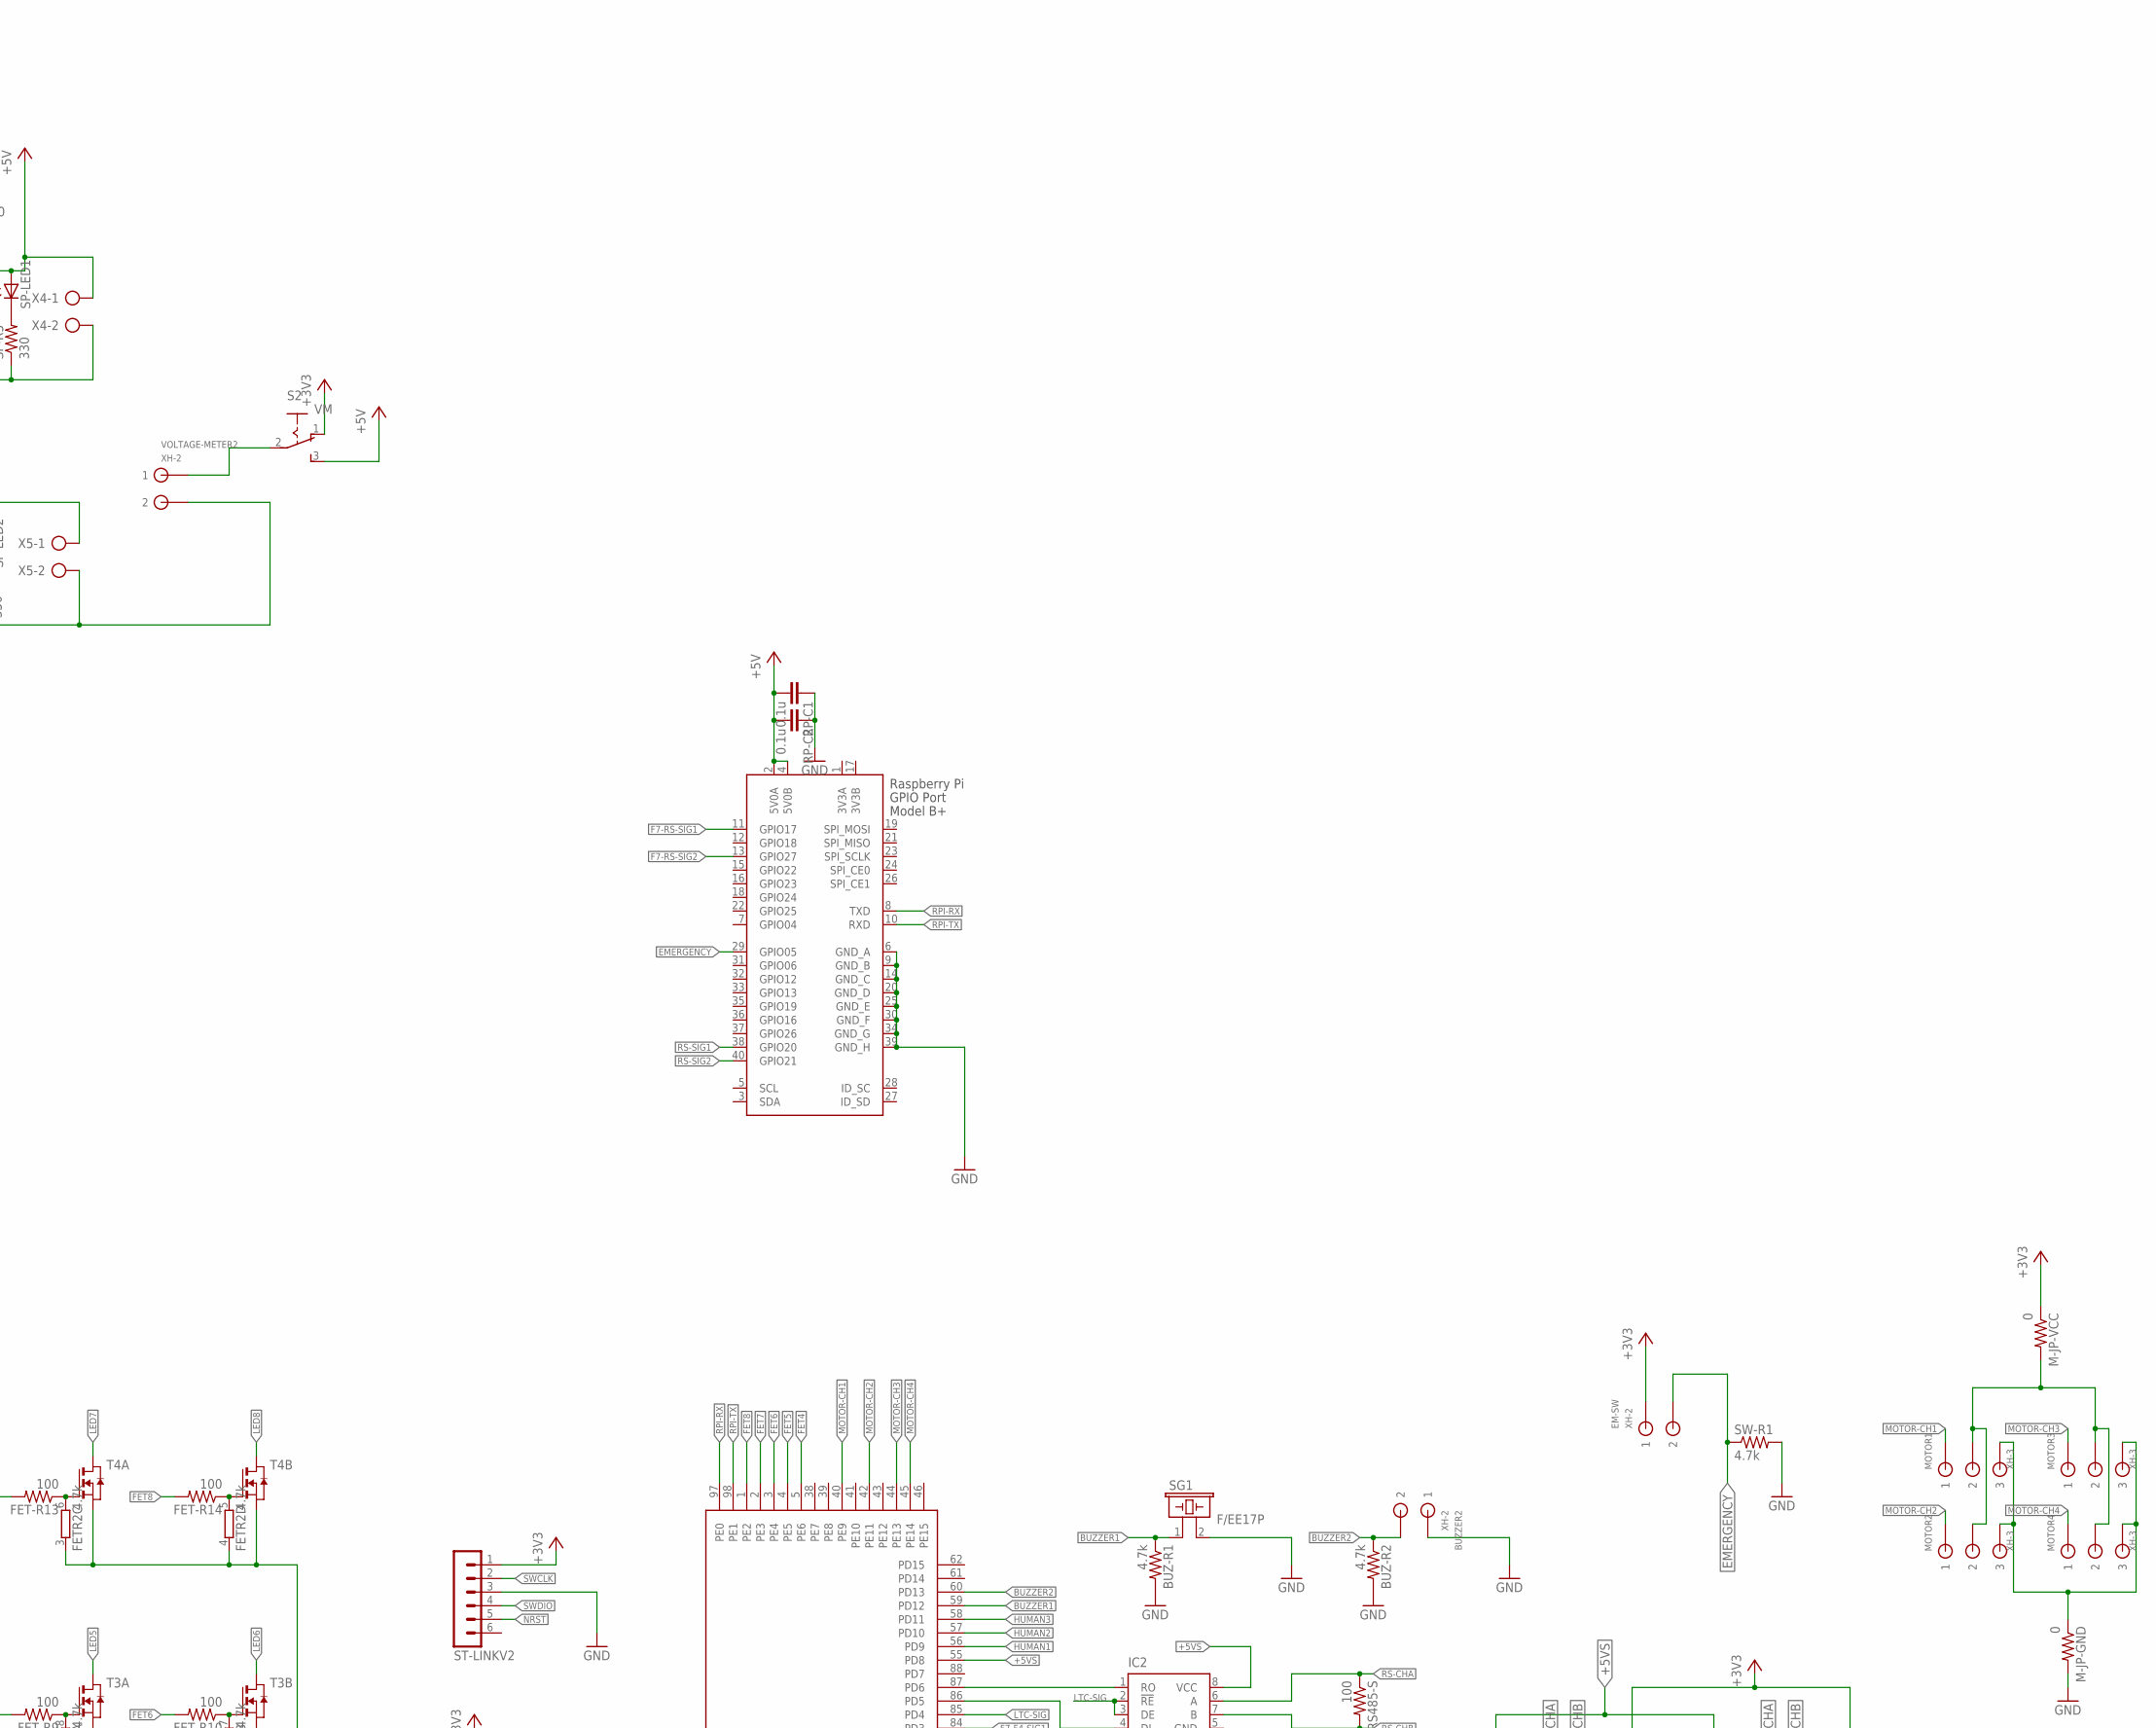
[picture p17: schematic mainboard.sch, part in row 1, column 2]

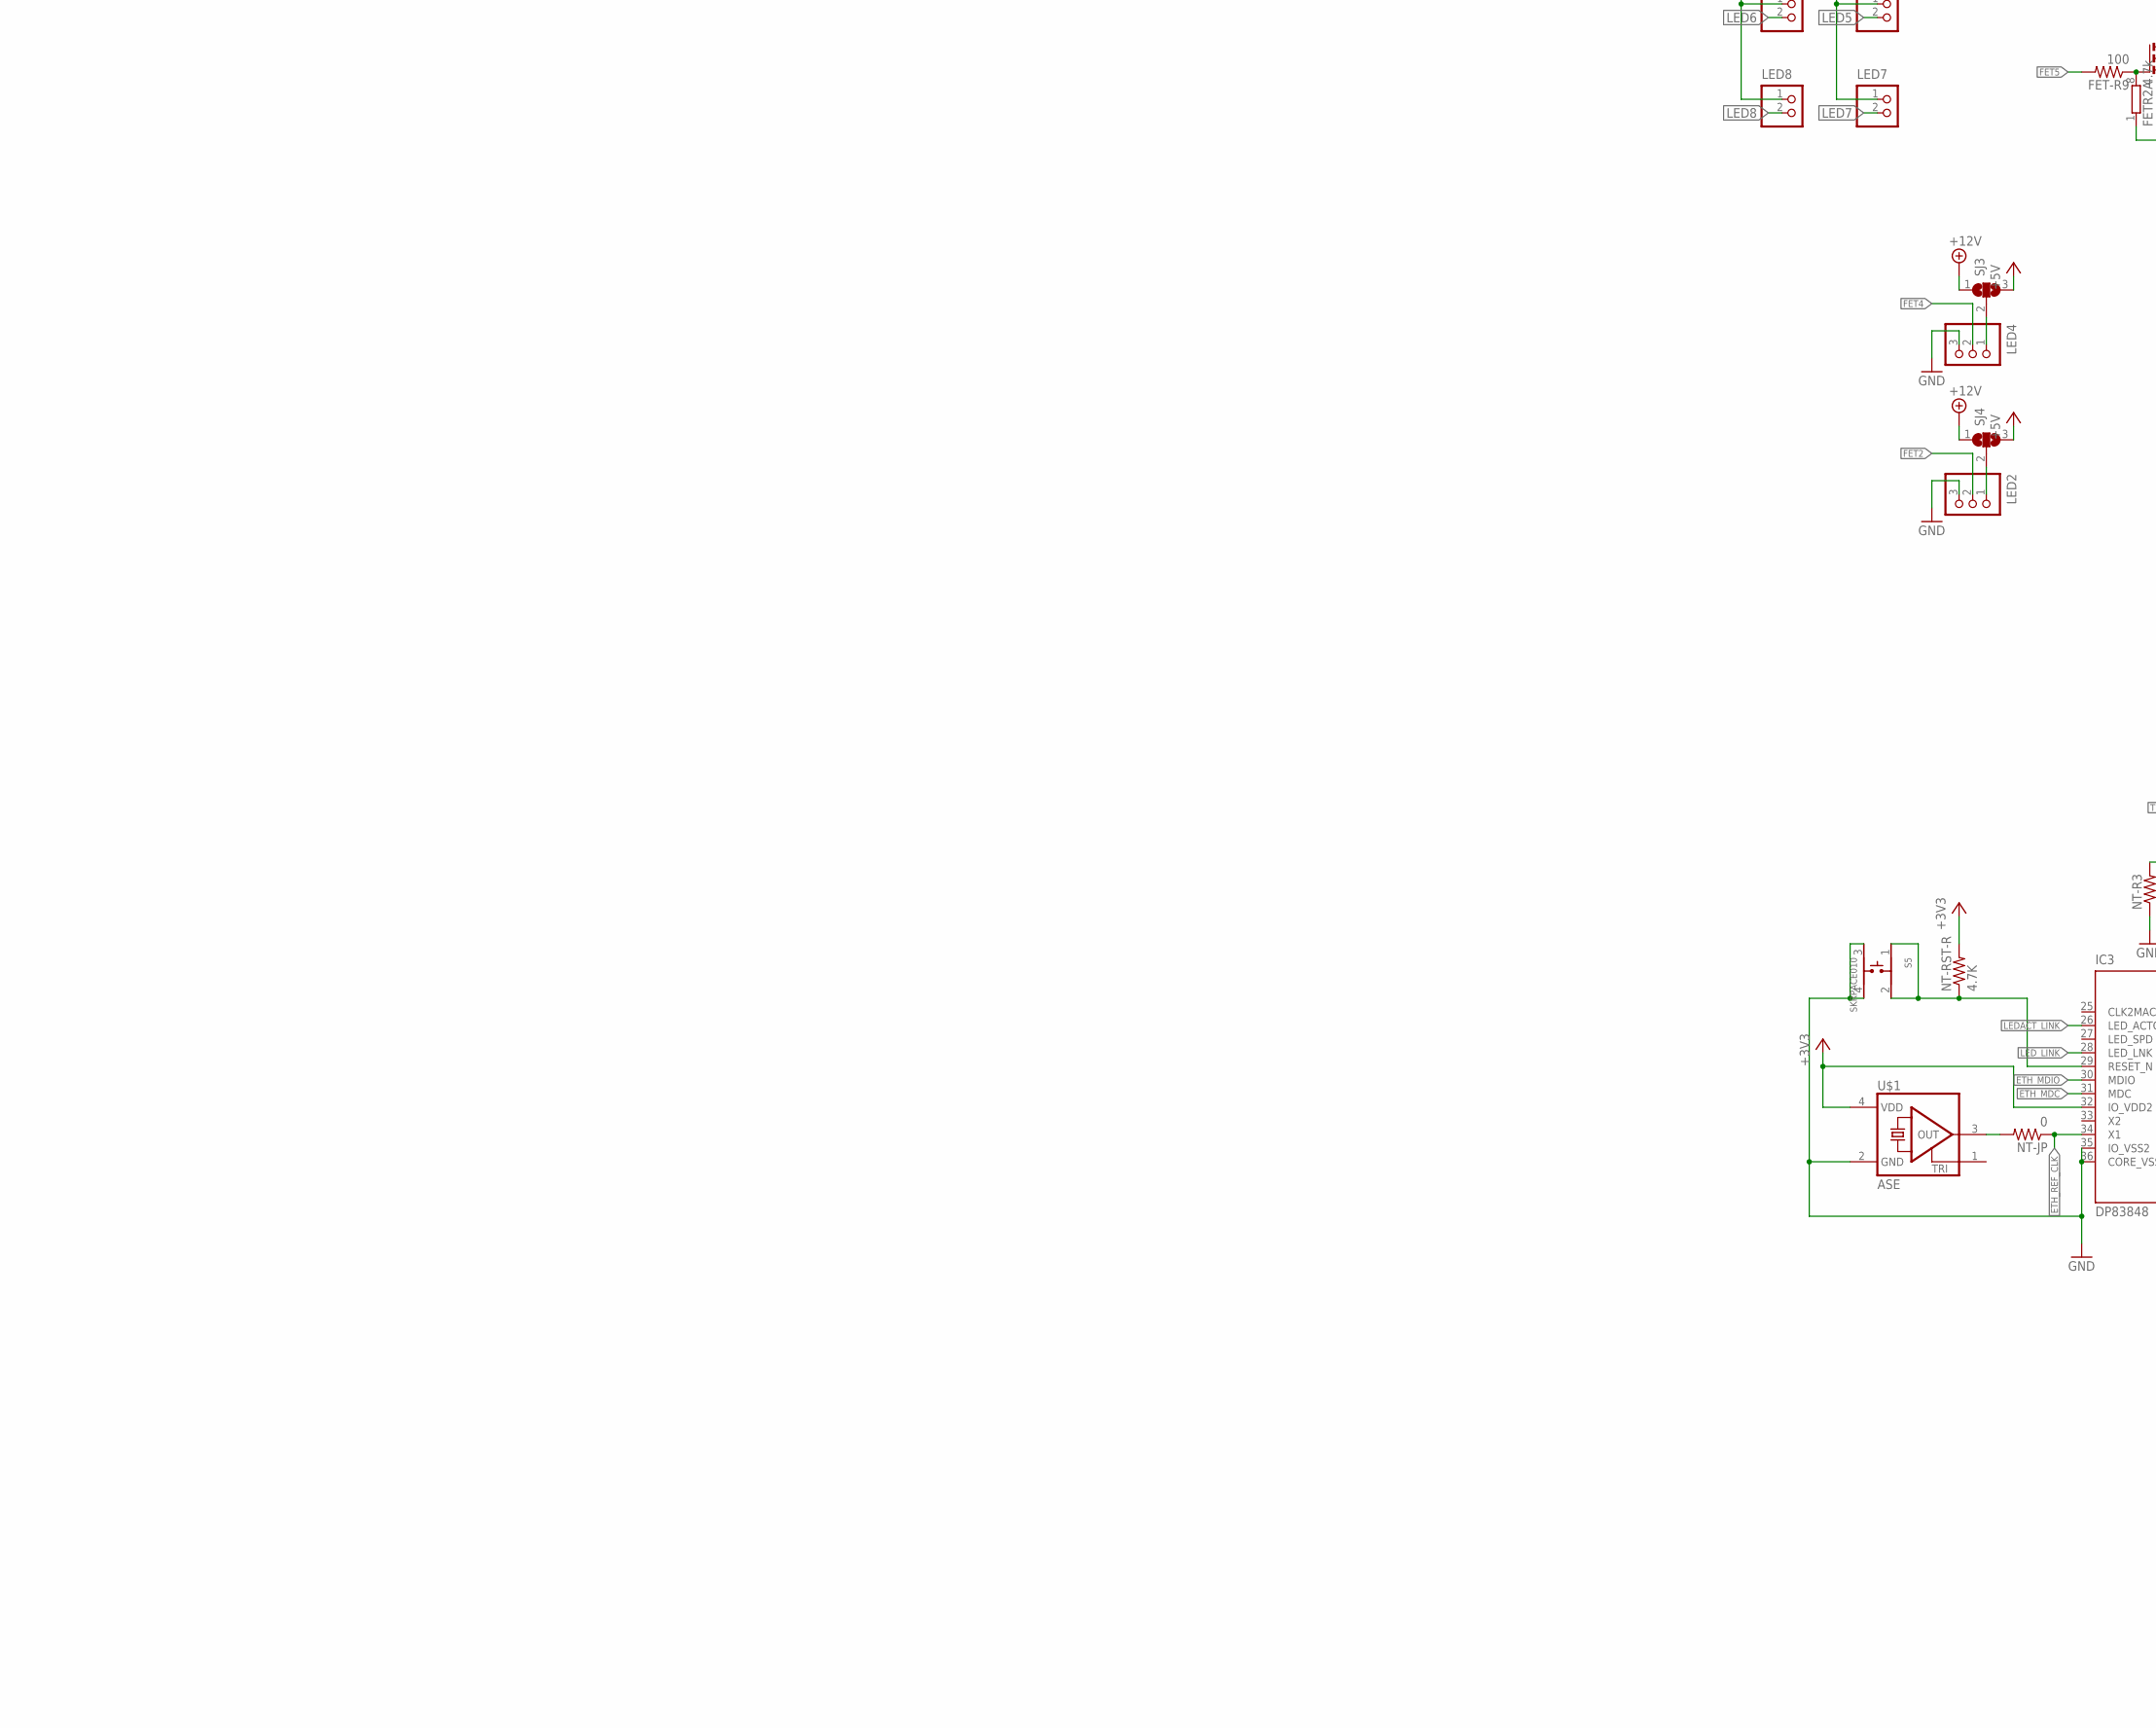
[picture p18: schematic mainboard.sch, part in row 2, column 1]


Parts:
3.3C1, 5C1, 9C1: 100u; D/7343-31R
3.3C2, 5C2, 5VS-C1, 12C2: 0.1u; C0805
3.3REG, 5VREG: OKL-T_6-W12N-C; OKL-T/3-W5
8MHZ: P-08669_HUSG-12.000-20; HC49U-V
100: 330; R0805
ADC1, ADC2, ADC3, ADC4: XH-3; CON3
BAT-JP1: 0; R0805
BAT-R1: 2.2k; R0805
BAT-R2: 330; R0805
BOOT0-STM: DTS-6
BUZ-R1, BUZ-R2: 4.7k; R0805
BUZZER2: XH-2; CON2
C1, C3: 22uF25V; C2012
C2, C4: 10uF10V; C2012
C5, C6: 22pF; C1608
CAN-C1: 4.7u; C0805
CAN-R1, CAN-R2: 51; R0805
CN1: P-04809_RJLD260TC1; RJ45_PULSEJACK
EM-SW: XH-2; CON2
FET-R9, FET-R10, FET-R13, FET-R14: 100; R0805
FETR2: 4.7k; EXBN8V
GND-CH: GND; SMD2,54-5,08
GND-CHK, GND-CHK1: GND; 2,15/1,0
HUMAN1, HUMAN2, HUMAN3: XH-3; CON3
I2C-R: XH-4; CON4
I2C-R1, I2C-R2: 4.7K; R0805
IC1: STM32F429VGT; LQFP100
IC2: LTC485N; DIL08
IC3: DP83848; LQFP48
IC4: MCP2561-E_P; DIP781W56P254L950H533Q8N
JP1: PINHD-1X2/90; 1X02/90
JY901: XH-4; CON4
LED1, LED2, LED3, LED4: B3P-VH
LED5, LED6, LED7, LED8: B2P-VH
LIPO: B3P-VH
M-JP-GND: 0; R0805
M-JP-VCC: 0; R0805
MAIN-SPL: XH-2; CON2
MAINSW2: MAIN; MA03-1
MOTOR1, MOTOR2, MOTOR3, MOTOR4: XH-3; CON3
MPU-SIG: XH-6; CON6
NT-C1, NT-C2, NT-C3, NT-C4, NT-C5: 0.1u; C0805
NT-JP: 0; R0805
NT-R1, NT-R2, NT-R4, NT-R5: 2k; R0805
NT-R3: 4.87k; R0805
NT-R6, NT-R7, NT-R8, NT-R9: 51; 0207/2V
NT-R10, NT-R11: 330; R0805
NT-RST-R: 4.7K; R0805
PING: XH-3; CON3
Q2, Q3, Q4, Q5: IRF9530; TO220BV
R1, R2: 1.2k; 0204/7
RESET-STM: DTS-6
RO1, RO2: XH-5; CON5
RO-R: 4.7k; EXBN8V
ROUTER: AK500/2-H
RP-C1, RP-C2: 0.1u; C0805
RS485-S: 100; R0805
S1, S2, S3: VM; M251
S4, S5: SKRPACE010; SW_SKRPACE010
SG1: F/EE17P
SJ1, SJ2, SJ3, SJ4: SJ2WW; SJ_2W
SP-LED1, SP-LED2: LEDCHIPLED_0805; CHIPLED_0805
SP-R1, SP-R3: 1.2k; R0805
SP-R2, SP-R4: 20K; R0805
SP-R5: 330; R0805
SP-R6, SP-R7, SP-R8: 4.7K; R0805
SP-RC1, SP-RC2: 20k; RTRIM3296W
SP-SW2: 219-02; CTS-219-02
SPI-R: XH-6; CON6
ST-LINKV2: MA06-1
STM-C1, STM-C2, STM-C3, STM-C4, STM-C5, STM-C6, STM-C7: 0.1u; C0805
STM-R1, STM-R2: 4.7K; R0805
SUOPPLY-SW2: XH-3; CON3
SW-R1: 4.7k; R0805
T3, T4: NMOS2SO8; SO8
TO-F7: ML14
TO-UI3: ML14
U$1: ASE
U$2: XT60
USB-POLY: 400mA; F0805MP
VOLTAGE-METER2: XH-2; CON2
X1: RASPI_BOARD_B+#_FP; RASPI_BOARD_B+_FULL_PAD
X2: DCJACK-MJ179P; MJ-179P
X3: C-07674_USB-A; PN87520-S
X4, X5, X6: AK500/2
XB1: XBEE-PRO
XBEE-RST: 4.7K; R0805

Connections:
3V3-SW: Q2.G, S3.1 (O), SP-R7.1, TO-UI3.6
3V3A: X1.1 (3V3A)
3V3B: X1.17 (3V3B)
5V-SW: Q4.G, S1.1 (O), SP-R8.1, TO-UI3.5
12V-B: Q3.D, U$2.+ (VCC), X2.1
12V-SW: MAINSW2.1, Q5.G, SP-R6.1, SUOPPLY-SW2.P$1 (1), TO-UI3.4
+3V3: ADC1.P$2 (2), ADC2.P$2 (2), ADC3.P$2 (2), ADC4.P$2 (2), BOOT0-STM.1, BOOT0-STM.2, CN1.3 (TCT), CN1.6 (RCT), CN1.9 (LED1_A), CN1.12 (LED2_A), EM-SW.P$1 (1), HUMAN1.P$1 (1), HUMAN2.P$1 (1), HUMAN3.P$1 (1), I2C-R.P$4 (4), I2C-R1.1, I2C-R2.1, IC1.6 (VBAT), IC1.11 (VDD), IC1.19 (VDD), IC1.21 (VREF+), IC1.22 (VDDA), IC1.28 (VDD), IC1.50 (VDD), IC1.75 (VDD), IC1.100 (VDD), IC3.22 (ANA33VDD), IC3.32 (IO_VDD2), IC3.48 (IO_VDD1), JY901.P$4 (4), M-JP-VCC.1, MPU-SIG.P$6 (6), NT-C1.2, NT-C4.1, NT-R1.2, NT-R2.2, NT-R4.2, NT-R5.2, NT-R6.1, NT-R7.2, NT-R8.2, NT-R9.1, NT-RST-R.2, Q2.D, RO-R.1, RO-R.2 (1), RO-R.3 (1), RO-R.4 (1), S2.1 (O), SP-LED2.A, SPI-R.P$6 (6), ST-LINKV2.1, STM-C1.2, STM-C2.2, STM-C3.2, STM-C4.2, STM-C7.2, STM-R1.2, U$1.4 (VDD), X5.1, XB1.1 (VCC), XB1.14 (VREF), XBEE-RST.2
+3V3S: 3.3C1.+, 3.3C2.1, 3.3REG.4 (VOUT), 3.3REG.5 (SENSE), C4.1, Q2.S, R2.1, SP-R7.2, TO-UI3.12
+5V: Q4.D, RP-C1.2, RP-C2.2, S2.3 (S), SJ1.3, SJ2.3, SJ3.3, SJ4.3, SP-LED1.A, X1.2 (5V0A), X1.4 (5V0B), X4.1
+5VS: 5C1.+, 5C2.1, 5VREG.4 (VOUT), 5VREG.5 (SENSE), 5VS-C1.1, C2.1, IC1.55 (PD8), IC2.8 (VCC), IC4.3 (VDD), JP1.1, PING.P$2 (2), Q4.S, R1.1, RO1.P$1 (1), RO2.P$1 (1), ROUTER.1, SP-R8.2, TO-UI3.7, USB-POLY.1
+12V: 3.3REG.2 (VIN), 5VREG.2 (VIN), 9C1.+, 12C2.1, C1.1, C3.1, LED5.1, LED6.1, LED7.1, LED8.1, MAIN-SPL.P$1 (1), Q5.D, SJ1.1, SJ2.1, SJ3.1, SJ4.1, SP-R2.2, SP-R4.2, TO-F7.14, TO-UI3.14, X6.1
+12VS: Q3.S, Q5.S, SP-R6.2, TO-UI3.3
ADC1: ADC1.P$1 (1), IC1.36 (PB1)
ADC2: ADC2.P$1 (1), IC1.35 (PB0)
ADC3: ADC3.P$1 (1), IC1.18 (PC3)
ADC4: ADC4.P$1 (1), IC1.17 (PC2)
BOOT0: BOOT0-STM.3, BOOT0-STM.4, IC1.94 (BOOT0), STM-R2.1, TO-UI3.8
BOOT-RX: IC1.69 (PA10), XB1.2 (DOUT)
BOOT-TX: IC1.68 (PA9), XB1.3 (DIN/!CONFIG)
BUZZER1: BUZ-R1.1, IC1.59 (PD12), SG1.1
BUZZER2: BUZ-R2.1, BUZZER2.P$2 (2), IC1.60 (PD13)
CAN-H: CAN-R1.2, IC4.7 (CANH), TO-F7.8
CAN-L: CAN-R2.2, IC4.6 (CANL), TO-F7.7
CAN-RX: IC1.91 (PB5), IC4.1 (TXD)
CAN-TX: IC1.92 (PB6), IC4.4 (RXD)
EMERGENCY: EM-SW.P$2 (2), IC1.15 (PC0), SW-R1.1, TO-F7.2, X1.29 (GPIO05)
ETH_CRS_DV: IC1.32 (PA7), IC3.40 (CRS), NT-R1.1
ETH_MDC: IC1.16 (PC1), IC3.31 (MDC)
ETH_MDIO: IC1.25 (PA2), IC3.30 (MDIO)
ETH_REF_CLK: IC1.24 (PA1), IC3.34 (X1), NT-JP.1
ETH_RXD0: IC1.33 (PC4), IC3.43 (RXD_0)
ETH_RXD1: IC1.34 (PC5), IC3.44 (RXD_1)
ETH_TXD0: IC1.51 (PB12), IC3.3 (TXD_0)
ETH_TXD1: IC1.52 (PB13), IC3.4 (TXD_1)
ETH_TX_EN: IC1.48 (PB11), IC3.2 (TX_EN)
F7-F4-SIG1: IC1.84 (PD3), TO-F7.12
F7-F4-SIG2: IC1.83 (PD2), TO-F7.11
F7-RS-SIG1: TO-F7.10, X1.11 (GPIO17)
F7-RS-SIG2: TO-F7.9, X1.13 (GPIO27)
FET1: IC1.9 (PC15), LED1.2
FET2: IC1.8 (PC14), LED2.2
FET3: IC1.7 (PC13), LED3.2
FET4: IC1.5 (PE6), LED4.2
FET5: FET-R9.2, IC1.4 (PE5)
FET6: FET-R10.2, IC1.3 (PE4)
FET7: FET-R13.2, IC1.2 (PE3)
FET8: FET-R14.2, IC1.1 (PE2)
GND: 3.3C1.-, 3.3C2.2, 3.3REG.3 (GND_1), 3.3REG.7 (GND_2), 5C1.-, 5C2.2, 5VREG.3 (GND_1), 5VREG.7 (GND_2), 5VS-C1.2, 9C1.-, 12C2.2, 100.1, ADC1.P$3 (3), ADC2.P$3 (3), ADC3.P$3 (3), ADC4.P$3 (3), BAT-R2.2, BUZ-R1.2, BUZ-R2.2, BUZZER2.P$1 (1), C1.2, C2.2, C3.2, C4.2, C5.1, C6.1, CAN-C1.1, CN1.4 (GND1), CN1.5 (GND2), FETR2.1, FETR2.2 (1), FETR2.3 (1), FETR2.4 (1), GND-CH.1, GND-CHK.1, GND-CHK1.1, HUMAN1.P$3 (3), HUMAN2.P$3 (3), HUMAN3.P$3 (3), I2C-R.P$1 (1), IC1.10 (VSS), IC1.20 (VSSA), IC1.27 (VSS), IC1.74 (VSS), IC1.99 (VSS), IC2.5 (GND), IC3.15 (CDVSS), IC3.19 (ANA18VSS), IC3.35 (IO_VSS2), IC3.36 (CORE_VSS), IC3.47 (IO_VSS1), IC4.2 (VSS), IC4.8 (STBY), JP1.2, JY901.P$1 (1), LED1.3, LED2.3, LED3.3, LED4.3, LIPO.2, M-JP-GND.2, MAIN-SPL.P$2 (2), MAINSW2.2, MPU-SIG.P$2 (2), NT-C1.1, NT-C3.1, NT-C4.2, NT-C5.2, NT-R3.1, PING.P$3 (3), Q3.G, R1.2, R2.2, RESET-STM.1, RESET-STM.2, RO1.P$2 (2), RO1.P$5 (5), RO2.P$2 (2), RO2.P$5 (5), ROUTER.2, RP-C1.1, RP-C2.1, S1.2, S3.2, S4.1, S4.2, S5.3, S5.4, SG1.2, SP-R1.1, SP-R3.1, SP-R5.1, SP-SW2.3, SP-SW2.4, SPI-R.P$2 (2), ST-LINKV2.3, STM-C1.1, STM-C2.1, STM-C3.1, STM-C4.1, STM-C5.2, STM-C6.2, STM-C7.1, STM-R2.2, SUOPPLY-SW2.P$2 (2), SW-R1.2, T3.1 (S), T3.3 (S), T4.1 (S), T4.3 (S), TO-F7.1, TO-UI3.13, U$1.2 (GND), U$2.- (GND), VOLTAGE-METER2.P$2 (2), X1.6 (GND_A), X1.9 (GND_B), X1.14 (GND_C), X1.20 (GND_D), X1.25 (GND_E), X1.30 (GND_F), X1.34 (GND_G), X1.39 (GND_H), X2.2, X3.4, X3.S1, X3.S2, X4.2, X5.2, X6.2, XB1.10 (GND)
HUMAN1: HUMAN1.P$2 (2), IC1.56 (PD9), TO-F7.4
HUMAN2: HUMAN2.P$2 (2), IC1.57 (PD10)
HUMAN3: HUMAN3.P$2 (2), IC1.58 (PD11)
LED5: LED5.2, T3.7 (D), T3.8 (D)
LED6: LED6.2, T3.5 (D), T3.6 (D)
LED7: LED7.2, T4.7 (D), T4.8 (D)
LED8: LED8.2, T4.5 (D), T4.6 (D)
LEDACT_LINK: IC3.26 (LED_ACTCOL), NT-R10.1
LED_LINK: IC3.28 (LED_LNK), NT-R11.1
LIPO: BAT-R1.1, LIPO.1, TO-F7.13, TO-UI3.1
LTC-SIG: IC1.85 (PD4), IC2.2 (!RE), IC2.3 (DE)
MISO: IC1.79 (PC11), MPU-SIG.P$4 (4), SPI-R.P$4 (4)
MOSI: IC1.80 (PC12), MPU-SIG.P$3 (3), SPI-R.P$3 (3)
MOTOR-CH1: IC1.40 (PE9), MOTOR1.P$1 (1)
MOTOR-CH2: IC1.42 (PE11), MOTOR2.P$1 (1)
MOTOR-CH3: IC1.44 (PE13), MOTOR3.P$1 (1)
MOTOR-CH4: IC1.45 (PE14), MOTOR4.P$1 (1)
MOTOR-FET: LIPO.3, TO-UI3.2
MPU-SIG: IC1.81 (PD0), MPU-SIG.P$1 (1)
unnamed: IC1.73 (VCAP2), STM-C5.1
unnamed: IC1.49 (VCAP1), STM-C6.1
unnamed: SP-R1.2, SP-RC1.1 (A), SP-RC1.2 (S)
unnamed: CAN-C1.2, CAN-R1.1, CAN-R2.1
unnamed: SP-LED1.C, SP-R5.2
unnamed: NT-JP.2, U$1.3 (OUT)
unnamed: SP-R3.2, SP-RC2.1 (A), SP-RC2.2 (S)
unnamed: IC3.29 (RESET_N), NT-RST-R.1, S5.1, S5.2
unnamed: 5VREG.6 (TRIM), SP-RC1.3 (E)
unnamed: IC3.23 (REG_OUT), NT-C2.2
unnamed: S2.2, VOLTAGE-METER2.P$1 (1)
unnamed: 3.3REG.6 (TRIM), SP-RC2.3 (E)
unnamed: 3.3REG.1 (ON/OFF), SP-R4.1, SP-SW2.1
unnamed: IC3.39 (RX_DV), NT-R2.1
unnamed: LED3.1, SJ1.2
unnamed: IC3.21 (IP_PH_P), NT-R4.1
unnamed: IC1.87 (PD6), IC2.1 (RO)
unnamed: IC1.86 (PD5), IC2.4 (DI)
unnamed: IC3.24 (VREF), NT-C2.1, NT-R3.2
unnamed: IC3.20 (IP_PH_M), NT-R5.1
unnamed: IC3.18 (ANA18VDD), NT-C3.2
unnamed: 100.2, SP-LED2.C
unnamed: 8MHZ.1, C6.2, IC1.13 (OSC_OUT)
unnamed: 5VREG.1 (ON/OFF), SP-R2.1, SP-SW2.2
unnamed: BAT-JP1.2, IC1.26 (PA3)
unnamed: IC3.37 (CORE_VDD), NT-C5.1
unnamed: 8MHZ.2, C5.2, IC1.12 (OSC_IN)
unnamed: LED1.1, SJ2.2
unnamed: CN1.10 (LED1_K), NT-R10.2
unnamed: CN1.11 (LED2_K), NT-R11.2
unnamed: BAT-JP1.1, BAT-R1.2, BAT-R2.1
unnamed: LED4.1, SJ3.2
unnamed: M-JP-VCC.2, MOTOR1.P$2 (2), MOTOR2.P$2 (2), MOTOR3.P$2 (2), MOTOR4.P$2 (2)
unnamed: LED2.1, SJ4.2
unnamed: M-JP-GND.1, MOTOR1.P$3 (3), MOTOR2.P$3 (3), MOTOR3.P$3 (3), MOTOR4.P$3 (3)
unnamed: S4.3, S4.4, XB1.5 (!RESET), XBEE-RST.1
unnamed: USB-POLY.2, X3.1
unnamed: FET-R10.1, FETR2.7 (2), T3.4 (G)
unnamed: FET-R9.1, FETR2.8 (2), T3.2 (G)
unnamed: FET-R14.1, FETR2.5 (2), T4.4 (G)
unnamed: FET-R13.1, FETR2.6 (2), T4.2 (G)
NRST: IC1.14 (NRST), RESET-STM.3, RESET-STM.4, ST-LINKV2.5, STM-R1.1, TO-UI3.9
PING: IC1.93 (PB7), PING.P$1 (1)
RD+: CN1.7 (RX+), IC3.14 (TPRDP), NT-R8.1
RD-: CN1.8 (RX-), IC3.13 (TPRDM), NT-R9.2
RO1-CHA: IC1.63 (PC6), RO1.P$3 (3), RO-R.8 (2)
RO1-CHB: IC1.64 (PC7), RO1.P$4 (4), RO-R.7 (2)
RO2-CHA: IC1.30 (PA5), RO2.P$3 (3), RO-R.6 (2)
RO2-CHB: IC1.89 (PB3), RO2.P$4 (4), RO-R.5 (2)
RPI-RX: IC1.97 (PE0), X1.8 (TXD)
RPI-TX: IC1.98 (PE1), X1.10 (RXD)
RS-CHA: IC2.6 (A), RS485-S.1, TO-F7.6
RS-CHB: IC2.7 (B), RS485-S.2, TO-F7.5
RS-SIG1: IC1.96 (PB9), X1.38 (GPIO20)
RS-SIG2: IC1.95 (PB8), X1.40 (GPIO21)
SCK: IC1.78 (PC10), MPU-SIG.P$5 (5), SPI-R.P$5 (5)
SCL: I2C-R.P$2 (2), I2C-R1.2, IC1.67 (PA8), JY901.P$2 (2)
SDA: I2C-R.P$3 (3), I2C-R2.2, IC1.66 (PC9), JY901.P$3 (3)
SPI-R-SS: IC1.82 (PD1), SPI-R.P$1 (1)
SWCLK: IC1.76 (PA14), ST-LINKV2.2, TO-UI3.10
SWDIO: IC1.72 (PA13), ST-LINKV2.4, TO-UI3.11
TD+: CN1.1 (TX+), IC3.17 (TPTDP), NT-R6.2
TD-: CN1.2 (TX-), IC3.16 (TPTDM), NT-R7.1
USB-D+: IC1.54 (PB15), X3.3
USB-D-: IC1.53 (PB14), X3.2

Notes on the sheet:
GNDガード敷く
Max DC25V

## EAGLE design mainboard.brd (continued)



Board: 2 copper layers, 144.9 x 134.8 mm, 156 parts (4 on the bottom side), 130 nets.

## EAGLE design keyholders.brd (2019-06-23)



Board: 2 copper layers, 95.6 x 85.2 mm, 114 parts (12 on the bottom side), 108 nets.

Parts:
C1, C2, C3, C4, C5, C6, C7, C8, C9, C10, C11, C12: 0.1u; C1608
FT-R1, FT-R2, FT-R5, FT-R7, FT-R8, FT-R11, FT-R13, FT-R14, FT-R17, FT-R19, FT-R20, FT-R23, FT-R25, FT-R26, FT-R29, FT-R31, FT-R32, FT-R35: 330; R0805
FT-R3, FT-R4, FT-R9, FT-R10, FT-R15, FT-R16, FT-R21, FT-R22, FT-R27, FT-R28, FT-R33, FT-R34: 27; R0805
FT-R6, FT-R12, FT-R18, FT-R24, FT-R30, FT-R36: 100; R0805
IC1, IC4, IC6, IC8, IC10, IC12: LIS3LV02DQ; QFPN-28
IC2, IC3, IC5, IC7, IC9, IC11: FT230XS; SSOP16
LED1, LED2, LED3, LED4, LED5, LED6: CHIP-LED0805
RX-LED, RX-LED1, RX-LED2, RX-LED3, RX-LED4, RX-LED5: CHIP-LED0805
SV1, SV2, SV3, SV4, SV5, SV6: MA05-1
TX-LED, TX-LED1, TX-LED2, TX-LED3, TX-LED4, TX-LED5: CHIP-LED0805
U$1, U$2, U$9, U$13, U$17, U$21: USB-PAD; USB
U$3, U$4, U$10, U$14, U$18, U$22: I-05318_ＮＳＳＷ１５７Ｔ; NSSW157T
U$5, U$7, U$11, U$15, U$19, U$23: CARROT
U$6, U$8, U$12, U$16, U$20, U$24: DDPROJECT2-TOP
USB-POLY1, USB-POLY2, USB-POLY3, USB-POLY4, USB-POLY5, USB-POLY6: 350mA; F0805MP

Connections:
+3V3-FT: C2.1, FT-R1.2, FT-R2.2, IC3.3, IC3.10, IC3.11, SV1.2
+3V3-FT1: C4.1, FT-R7.2, FT-R8.2, IC2.3, IC2.10, IC2.11, SV2.2
+3V3-FT2: C6.1, FT-R13.2, FT-R14.2, IC5.3, IC5.10, IC5.11, SV3.2
+3V3-FT3: C8.1, FT-R19.2, FT-R20.2, IC7.3, IC7.10, IC7.11, SV4.2
+3V3-FT4: C10.1, FT-R25.2, FT-R26.2, IC9.3, IC9.10, IC9.11, SV5.2
+3V3-FT5: C12.1, FT-R31.2, FT-R32.2, IC11.3, IC11.10, IC11.11, SV6.2
GND: IC1.2, IC1.5, IC1.17
GND1: IC4.2, IC4.5, IC4.17
GND2: IC6.2, IC6.5, IC6.17
GND3: IC8.2, IC8.5, IC8.17
GND4: IC10.2, IC10.5, IC10.17
GND5: IC12.2, IC12.5, IC12.17
GNDA: C1.2, C2.2, IC3.5, IC3.13, LED3.C, SV1.5, U$2.GND, U$3.CATHODE
GNDA1: C3.2, C4.2, IC2.5, IC2.13, LED1.C, SV2.5, U$1.GND, U$4.CATHODE
GNDA2: C5.2, C6.2, IC5.5, IC5.13, LED2.C, SV3.5, U$9.GND, U$10.CATHODE
GNDA3: C7.2, C8.2, IC7.5, IC7.13, LED4.C, SV4.5, U$13.GND, U$14.CATHODE
GNDA4: C9.2, C10.2, IC9.5, IC9.13, LED5.C, SV5.5, U$17.GND, U$18.CATHODE
GNDA5: C11.2, C12.2, IC11.5, IC11.13, LED6.C, SV6.5, U$21.GND, U$22.CATHODE
unnamed: FT-R9.1, IC2.8
unnamed: FT-R10.1, IC2.9
unnamed: FT-R8.1, RX-LED1.A
unnamed: FT-R7.1, TX-LED1.A
unnamed: FT-R9.2, U$1.D+
unnamed: FT-R10.2, U$1.D-
unnamed: U$1.VCC, USB-POLY2.2
unnamed: FT-R11.1, LED1.A
unnamed: FT-R12.1, U$4.ANODE
unnamed: FT-R15.1, IC5.8
unnamed: FT-R16.1, IC5.9
unnamed: FT-R14.1, RX-LED2.A
unnamed: FT-R13.1, TX-LED2.A
unnamed: FT-R15.2, U$9.D+
unnamed: FT-R16.2, U$9.D-
unnamed: U$9.VCC, USB-POLY3.2
unnamed: FT-R17.1, LED2.A
unnamed: FT-R18.1, U$10.ANODE
unnamed: FT-R2.1, RX-LED.A
unnamed: FT-R1.1, TX-LED.A
unnamed: FT-R21.1, IC7.8
unnamed: FT-R3.2, U$2.D+
unnamed: FT-R3.1, IC3.8
unnamed: FT-R4.1, IC3.9
unnamed: FT-R4.2, U$2.D-
unnamed: FT-R22.1, IC7.9
unnamed: U$2.VCC, USB-POLY1.2
unnamed: FT-R5.1, LED3.A
unnamed: FT-R6.1, U$3.ANODE
unnamed: FT-R20.1, RX-LED3.A
unnamed: FT-R19.1, TX-LED3.A
unnamed: FT-R21.2, U$13.D+
unnamed: FT-R22.2, U$13.D-
unnamed: U$13.VCC, USB-POLY4.2
unnamed: FT-R23.1, LED4.A
unnamed: FT-R24.1, U$14.ANODE
unnamed: FT-R27.1, IC9.8
unnamed: FT-R28.1, IC9.9
unnamed: FT-R26.1, RX-LED4.A
unnamed: FT-R25.1, TX-LED4.A
unnamed: FT-R27.2, U$17.D+
unnamed: FT-R28.2, U$17.D-
unnamed: U$17.VCC, USB-POLY5.2
unnamed: FT-R29.1, LED5.A
unnamed: FT-R30.1, U$18.ANODE
unnamed: FT-R33.1, IC11.8
unnamed: FT-R34.1, IC11.9
unnamed: FT-R32.1, RX-LED5.A
unnamed: FT-R31.1, TX-LED5.A
unnamed: FT-R33.2, U$21.D+
unnamed: FT-R34.2, U$21.D-
unnamed: U$21.VCC, USB-POLY6.2
unnamed: FT-R35.1, LED6.A
unnamed: FT-R36.1, U$22.ANODE
RXD: IC3.4, SV1.3
RXD1: IC2.4, SV2.3
RXD2: IC5.4, SV3.3
RXD3: IC7.4, SV4.3
RXD4: IC9.4, SV5.3
RXD5: IC11.4, SV6.3
RXLED: IC3.14, RX-LED.C
RXLED1: IC2.14, RX-LED1.C
RXLED2: IC5.14, RX-LED2.C
RXLED3: IC7.14, RX-LED3.C
RXLED4: IC9.14, RX-LED4.C
RXLED5: IC11.14, RX-LED5.C
TXD: IC3.1, SV1.4
TXD1: IC2.1, SV2.4
TXD2: IC5.1, SV3.4
TXD3: IC7.1, SV4.4
TXD4: IC9.1, SV5.4
TXD5: IC11.1, SV6.4
TXLED: IC3.7, TX-LED.C
TXLED1: IC2.7, TX-LED1.C
TXLED2: IC5.7, TX-LED2.C
TXLED3: IC7.7, TX-LED3.C
TXLED4: IC9.7, TX-LED4.C
TXLED5: IC11.7, TX-LED5.C
V+: C1.1, FT-R5.2, FT-R6.2, IC3.12, SV1.1, USB-POLY1.1
V+1: C3.1, FT-R11.2, FT-R12.2, IC2.12, SV2.1, USB-POLY2.1
V+2: C5.1, FT-R17.2, FT-R18.2, IC5.12, SV3.1, USB-POLY3.1
V+3: C7.1, FT-R23.2, FT-R24.2, IC7.12, SV4.1, USB-POLY4.1
V+4: C9.1, FT-R29.2, FT-R30.2, IC9.12, SV5.1, USB-POLY5.1
V+5: C11.1, FT-R35.2, FT-R36.2, IC11.12, SV6.1, USB-POLY6.1
VDD: IC1.3, IC1.19
VDD1: IC4.3, IC4.19
VDD2: IC6.3, IC6.19
VDD3: IC8.3, IC8.19
VDD4: IC10.3, IC10.19
VDD5: IC12.3, IC12.19

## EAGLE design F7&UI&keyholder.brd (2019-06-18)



Board: 2 copper layers, 100.0 x 100.0 mm, 68 parts (30 on the bottom side), 72 nets.

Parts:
3V3-FET, 5V-FET, 12V-FET: BSS123; SOT23
3V3-SW, 5V-SW: XH-3; CON3
12V-KEY, 12V-LED: XH-2; CON2
BAT-JP1: 0; R0805
BAT-R1: 2.2k; R0805
BAT-R2: 330; R0805
BUZ-R1: 4.7k; R0805
C1, C2: 0.1u; C1608
CAN-C1: 4.7u; C0805
CAN-R1, CAN-R2: 51; R0805
CN1, CN13: B3P-VH
FT-R1, FT-R2, FT-R5: 330; R0805
FT-R3, FT-R4: 27; R0805
FT-R6: 100; R0805
IC2: LTC485N; DIL08
IC3: FT230XS; SSOP16
IC4: MCP2561-E_P; DIP781W56P254L950H533Q8N
LED3: CHIP-LED0805
LED-R1, LED-R2, LED-R3: ?; M0805
LIPO-LED: XH-2; CON2
MOTOR-KEY: XH-2; CON2
MOTOR-LED: XH-2; CON2
R1, R3, R4: 4.7k; M0805
R2, R5, R6: 1k; M0805
RS485-S: 100; R0805
RX-LED: CHIP-LED0805
S1: 255SB
S3, S4: ST12-303FCG; ST12303FCG
SG1: F/EE17P
SJ1, SJ3: SJ_2W
ST-LINKV2: MA06-1
STM-C1, STM-C2: 0.1u; C0805
STM-R1, STM-R2: 4.7K; R0805
SV1: MA05-1
SW1: EDG-03
SW-R1, SW-R2: 330; R0805
TO-MAIN, TO-MAIN2: ML14
TX-LED: CHIP-LED0805
U$1: F7-DISCO-ARDUINO
U$2: USB-PAD; USB
U$3: I-05318_ＮＳＳＷ１５７Ｔ; NSSW157T
U$5: CARROT
U$6: DDPROJECT2-TOP
USB-POLY: 400mA; MF-5/1
USB-POLY1: 350mA; F0805MP
VOLTAGE: XH-2; CON2

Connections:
3V3-SW: 3V3-FET.3, TO-MAIN2.6
5V-SW: 5V-FET.3, TO-MAIN2.5
12V-SW: 12V-FET.3, TO-MAIN2.4
+3V3-FT: C2.1, FT-R1.2, FT-R2.2, IC3.3, IC3.10, IC3.11, SV1.2
+3V3S: S3.3, S3.4, ST-LINKV2.1, STM-R1.2, SW1.2, SW-R1.1, SW-R2.1, TO-MAIN2.12
+5V: IC2.8, IC4.3, SJ1.3, SJ3.3, U$1.5V
+5VS: SW1.1, TO-MAIN2.7
+9V: S1.2, SJ1.1, SJ3.1, U$1.VIN
+12V: S1.3, TO-MAIN.14
BOOT0: S3.1, S3.2, STM-R2.1, TO-MAIN2.8
BUZZER1: BUZ-R1.1, SG1.1, U$1.PA11
CAN1-RX: IC4.1, U$1.PB8
CAN1-TX: IC4.4, U$1.PB9
CAN-H: CAN-R1.2, IC4.7, TO-MAIN.8
CAN-L: CAN-R2.2, IC4.6, TO-MAIN.7
EMERGENCY: TO-MAIN.2, U$1.PA4
F7-F4-SIG1: TO-MAIN.12, U$1.PC8
F7-F4-SIG2: TO-MAIN.11, U$1.PJ0
F7-RS-SIG1: TO-MAIN.10, U$1.PJ3
F7-RS-SIG2: TO-MAIN.9, U$1.PF7
GND: BAT-R2.2, BUZ-R1.2, CAN-C1.1, CN1.3, CN13.3, IC2.5, IC4.2, IC4.8, SG1.2, STM-C1.1, STM-C2.1, TO-MAIN.1, U$1.GND1, U$1.GND@1, U$1.GND@2
GND2: 3V3-FET.2, 3V3-SW.P$3, 5V-FET.2, 5V-SW.P$3, 12V-FET.2, 12V-LED.P$2, LIPO-LED.P$2, MOTOR-LED.P$2, R1.1, R3.1, R4.1, S3.CATHODE, S4.3, S4.4, S4.CATHODE, ST-LINKV2.3, STM-R2.2, TO-MAIN2.13, VOLTAGE.P$2
GNDA: IC3.5, LED3.C, U$2.GND, U$3.CATHODE
HUMAN1: TO-MAIN.4, U$1.PA6
LED1: CN13.2, U$1.PB15
LED2: CN1.2, U$1.PB14
LIPO: BAT-R1.1, TO-MAIN.13
LIPO2: LED-R1.1, MOTOR-KEY.P$1, USB-POLY.1
LIPO-ADC: BAT-JP1.2, U$1.PF8
MOTOR-FET: LED-R2.1, MOTOR-KEY.P$2, TO-MAIN2.2
unnamed: CN1.1, SJ1.2
unnamed: 3V3-FET.1, R2.1, R4.2
unnamed: 5V-FET.1, R3.2, R5.1
unnamed: CAN-C1.2, CAN-R1.1, CAN-R2.1
unnamed: SW1.4, SW1.5, SW1.6, VOLTAGE.P$1
unnamed: 12V-FET.1, R1.2, R6.1
unnamed: 12V-KEY.P$2, R6.2
unnamed: 3V3-SW.P$1, R2.2
unnamed: 5V-SW.P$1, R5.2
unnamed: S4.ANODE, SW-R1.2
unnamed: S3.ANODE, SW-R2.2
unnamed: TO-MAIN2.1, USB-POLY.2
unnamed: LED-R1.2, LIPO-LED.P$1
unnamed: LED-R2.2, MOTOR-LED.P$1
unnamed: 12V-LED.P$1, LED-R3.2
unnamed: FT-R2.1, RX-LED.A
unnamed: FT-R1.1, TX-LED.A
unnamed: FT-R3.2, U$2.D+
unnamed: FT-R3.1, IC3.8
unnamed: FT-R4.1, IC3.9
unnamed: FT-R4.2, U$2.D-
unnamed: C1.2, C2.2, IC3.13, SV1.5
unnamed: U$2.VCC, USB-POLY1.2
unnamed: FT-R5.1, LED3.A
unnamed: FT-R6.1, U$3.ANODE
unnamed: BAT-JP1.1, BAT-R1.2, BAT-R2.1
unnamed: CN13.1, SJ3.2
NRST: S4.1, S4.2, ST-LINKV2.5, STM-R1.1, TO-MAIN2.9
RS-CHA: IC2.6, RS485-S.1, TO-MAIN.6
RS-CHB: IC2.7, RS485-S.2, TO-MAIN.5
RS-SIG: IC2.2, IC2.3, U$1.PJ1
RXD: IC3.4, SV1.3
RXLED: IC3.14, RX-LED.C
SWCLK: ST-LINKV2.2, TO-MAIN2.10
SWDIO: ST-LINKV2.4, TO-MAIN2.11
TXD: IC3.1, SV1.4
TXLED: IC3.7, TX-LED.C
USART6-RX: IC2.1, U$1.PC7
USART6-TX: IC2.4, U$1.PC6
V+: C1.1, FT-R5.2, FT-R6.2, IC3.12, SV1.1, USB-POLY1.1
VCC: STM-C1.2, STM-C2.2, U$1.3V, U$1.AVDD, U$1.IOREF
VDD: 3V3-SW.P$2, 5V-SW.P$2, 12V-KEY.P$1, LED-R3.1, SW1.3, TO-MAIN2.14

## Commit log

2019-06-08 #OTL 意外とやること多い
    [F7&UI&keyholder.brd, F7&UI&keyholder.sch, UIboard.dxf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]
2019-06-09 #update UI,F7 だいたい完成 #todo シルク
    [F7&UI&keyholder.brd, mainboard.brd, mainboard.sch]
2019-06-09 #update UI,F7 シルク官僚
    [F7&UI&keyholder.brd, F7&UI&keyholder.sch]
2019-06-17 #早く仕上げろー
    [Carrot.dxf, F7&Key&UI-shape.0003.ipt, F7&Key&UI-shape.ipt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]
2019-06-18 #update 大体完成 由利倫見れたら見てw
    [F7&UI&keyholder.brd, F7&UI&keyholder.sch, mainboard.brd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]
2019-06-19 #完成くらい
    [mainboard.sch]
2019-06-19 #update ほぼ完成、F7,UI,KeyHolder基板ガーバ出力済み、main基板はあとはベタ確認とシルク最終チェック。明日の夜発注する！
    [Carrot-order.xlsx, F7&UI&keyholder.sch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]
2019-06-20 #update UI teardrop メイン 少しベタ切った
    [UI&KeyHolder&F7-order.GBL, UI&KeyHolder&F7-order.GBO, UI&KeyHolder&F7-order.GBP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]
2019-06-20 #update ベタ切り、シルク調整
    [mainboard.sch]
2019-06-20 #update 塾から帰ってきたら、teardropしてCAMして八(*´ε`*)ﾁｭｯﾁｭ
2019-06-20 #finish 発注しました
    [UI&KeyHolder&F7-order.GBL, UI&KeyHolder&F7-order.GBO, UI&KeyHolder&F7-order.GBP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]
2019-06-23 #update 部品リスト
    [Carrot-order.xlsx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]
2019-06-29 #finish 部品発注完了
    [Carrot-order.xlsx, mainboard - コピー.brd, mainboard.dxf]

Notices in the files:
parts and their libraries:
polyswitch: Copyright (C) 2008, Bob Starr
